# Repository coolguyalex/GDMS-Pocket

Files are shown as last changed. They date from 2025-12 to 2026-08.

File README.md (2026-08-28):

# GDMS:Pocket
**Goblinoid Dungeon Mastering System** — microcontroller-based handheld random table roller for tabletop RPGs.

---

## Concept

A dungeon master's companion designed to stay out of the way until you need it. Pull it out, roll a name, an encounter, a room, or whatever your table demands, then put it back in your pocket. GDMS:Pocket is designed to be as ignorable as it is useful — no app, no screen glare, no dead battery notification from your phone mid-session.

Content lives on a microSD card as plain CSV files and JSON recipe files. Adding, removing, or editing tables requires nothing more than a computer and a text editor.

---

## Current Firmware: Alpha 10 

### Implemented Features

- Navigate categories corresponding to folders on the SD card
- Browse and select CSV tables or JSON recipe generators within each category
- Roll a random result with a single button press; re-roll instantly with the same button
- Scroll long results that exceed the screen height
- Hold UP/DOWN for fast scrolling through lists
- LED breathing animation indicates power-on state
- LED "pop" flash on every button press
- Passive buzzer feedback — distinct tones per button
- Full options menu (A+B combo from any screen):
  - Buzzer on/off and volume (loud/soft)
  - LED on/off, pop on/off, brightness (low/med/high)
  - Breath speed (fast/med/slow)
  - Sleep timeout (5 min / 10 min / 30 min / never)
  - Data Edit Mode — exposes the SD card as a USB mass storage drive
- Settings persist to SD card (`/DATA/settings.cfg`) and reload on boot
- Sleep mode: display blanks after inactivity timeout; any button wakes it (suspended while in Data Edit Mode)
- Live battery voltage indicator in the header — 3-bar icon with critical flash
- Header titles truncated with `...` if they would overlap the battery icon
- Startup splash screen (2 seconds on boot)
- About screen with control reference

### Data Edit Mode

Selecting "Data Edit" from the options menu puts the device into USB mass storage mode: the SD card mounts on the connected computer as a normal removable drive, so content can be added, edited, or removed with a regular file explorer — no card removal required. The device still charges normally over the same USB-C connection while in this mode.

- Entered from the options menu (A → cycles into the mode)
- Screen displays "DATA EDIT MODE" / "press A + B to exit." while active
- Exit via A+B (held) — the same combo used elsewhere to open the options menu is repurposed here to exit, since the options menu isn't reachable while the SD card is handed off to the host
- On exit, the SD card is unmounted from the host, remounted for the firmware's own file access, and categories are rescanned so any added/removed/edited content shows up immediately
- Implemented via Adafruit_TinyUSB's mass storage (MSC) class, using the same SdFat `SD` object already used for file-level access elsewhere in the firmware — read/write/flush callbacks operate at the raw sector level rather than the file level
- Sleep timeout is disabled while in this mode so the screen doesn't blank mid-transfer

### JSON Recipe System (V1)

JSON files in a category folder act as multi-part generators. A recipe chains together rolls from multiple CSV tables and assembles them into a single composed output. Features include optional parts (probability `p`), repeat counts, cross-category table references, and a `format` string for custom output layouts. See **Content & Customisation** below and the recipe convention document in the repo for full details.

### CSV Weighted Tables

If a CSV file uses two columns — `weight,entry` — the first column is treated as an integer weight and results are sampled proportionally. Single-column CSVs treat all entries as equally likely. Lines beginning with `#` or `//` are treated as comments and skipped.

---

## Hardware

### Bill of Materials

| Component | Description |
|---|---|
| Adafruit Feather RP2040 Adalogger | MCU + built-in microSD slot |
| 1.5" SH1107 OLED (SPI, 128×128) | Display |
| 4× momentary pushbutton | Navigation (active-low) |
| Passive buzzer module (3-pin) | Audio feedback |
| LED + current-limiting resistor | Status indicator |
| 3.7V LiPo battery (JST connector) | Power |
| 2× 100kΩ resistor | Battery voltage divider |

### BOM with cost estimates
|Component |Price |Source |
|---|---|---|
|Adafruit Feather RP2040 Adalogger |$14.95 |Adafruit / DigiKey, retail single unit|
|1.5” SH1107 128×128 monochrome OLED (SPI)|$4.50 |AliExpress, bulk 10-pack pricing |
|Momentary pushbuttons ×4 |$0.60 |AliExpress, bulk 100pc pack |
|Passive buzzer module |$0.35 |AliExpress, bulk pack |
|LED + resistor |$0.10 |AliExpress, bulk pack |
|3.7V LiPo battery w/ JST |$2.50 |AliExpress, bulk pack |
|100kΩ resistors ×2 |$0.02 |AliExpress, bulk reel |
|Slide switch |$0.30 |AliExpress, bulk pack |
|Custom PCB, bare board (10-unit batch) |$1.50 |PCBWay |
|3D printed PETG enclosure |$3.00 |Self-sourced filament |
|Misc wire/headers/hardware |$1.00 |AliExpress, bulk pack |
|**Total** |**$28.82**| |

### Pin Mapping

#### OLED Display (SH1107, Software SPI)

| OLED Pin | Feather Pin |
|---|---|
| VCC | 3V3 |
| GND | GND |
| SCL (CLK) | D13 |
| SDA (DATA) | D12 |
| DC | D11 |
| CS | D10 |
| RST | D9 |

> **Library patch required:** The U8g2 SH1107 128×128 driver sets `default_x_offset = 96` by default, which causes a 32px horizontal wrap on some panels. Set both `default_x_offset` and `flipmode_x_offset` to `0` in `u8x8_d_sh1107.c`. This must be re-applied after any U8g2 library update. See Log 8 for full details.
>
> This has recurred at least once in practice after installing an unrelated library (Adafruit TinyUSB) via Library Manager, which appears to have triggered a U8g2 reinstall/update as a side effect. Worth checking `default_x_offset`/`flipmode_x_offset` any time the display shows an unexplained horizontal shift, not just after deliberate U8g2 updates. As of U8g2's source (checked Feb 2025), the maintainer's own comment on this section confirms `0` is the correct value for panels like this one — see [olikraus/u8g2#2581](https://github.com/olikraus/u8g2/issues/2581).

#### Buttons (Active-Low, Internal Pull-Up)

| Button | Feather Pin |
|---|---|
| UP | A1 |
| DOWN | A2 |
| A (select / roll) | A3 |
| B (back) | 24 |

Buttons are wired pin → GND. No external pull-up resistors needed.

#### Buzzer (Passive, PWM)

| Signal | Feather Pin |
|---|---|
| SIG | D6 |
| VCC | 3V3 |
| GND | GND |

> A series resistor (~1kΩ) on the signal line is recommended to reduce volume to a comfortable level for table use.

#### LED

| Connection | Feather Pin |
|---|---|
| Anode (via resistor) | D25 |
| Cathode | GND |

> Do not use `PIN_LED` as a variable name — it is defined as a macro in the RP2040 Arduino core.

#### Battery Voltage Divider

The Feather RP2040 Adalogger does not have a built-in battery monitor circuit. An external voltage divider must be wired as follows:

```
VBAT ──[ 100kΩ ]──┬──[ 100kΩ ]── GND
                  │
                  └── A0
```

| Signal | Feather Pin |
|---|---|
| Divider center tap | A0 |

The firmware reads A0, multiplies by 2, and displays a 3-bar battery icon in the header. Voltage thresholds: FULL ≥4.0V, OK ≥3.7V, LOW ≥3.5V, CRIT <3.5V (flashing).

### SD Card

The Adalogger's built-in microSD slot is used via SdFat (Adafruit fork) on SPI1. Format the card as FAT32.

---

## SD Card Data Structure

```
/DATA/
  /category-name/
    table.csv
    generator.json
    _hidden-ingredient.csv
  /another-category/
    ...
  settings.cfg          ← written automatically by firmware
```

- `/DATA` is the root content directory. It must exist.
- Each immediate subfolder of `/DATA` becomes a navigable category in the UI.
- Folders nested deeper than one level are ignored.
- `.csv` and `.json` files within a category folder appear as selectable items.
- Files whose names begin with `_` are hidden from the UI but accessible to JSON recipes.
- `settings.cfg` is written automatically and should not be edited manually.

---

## Software

### Language & Framework

Arduino (C++) targeting the Adafruit Feather RP2040 Adalogger via the Arduino-Pico core.

### Library Dependencies

| Library | Purpose |
|---|---|
| U8g2 (olikraus) | OLED driver and graphics |
| SdFat – Adafruit Fork | microSD access |
| ArduinoJson | JSON recipe parsing |
| Adafruit TinyUSB | USB mass storage (Data Edit Mode) — requires Tools > USB Stack > Adafruit TinyUSB in Arduino IDE |

### Controls Reference

| Button | Category / File list | Table / Result view | Options menu | Data Edit Mode |
|---|---|---|---|---|
| UP | Scroll up | Scroll up | Previous option | — |
| DOWN | Scroll down | Scroll down | Next option | — |
| A | Select / enter | Re-roll | Cycle setting value | — |
| B | — (no-op at root) | Back to file list | Back | — |
| A + B (held) | Open options | Open options | — | Exit Data Edit Mode |

### Architecture Notes

- State machine with six modes: `MODE_CATS`, `MODE_FILES`, `MODE_TABLE`, `MODE_OPTIONS`, `MODE_ABOUT`, `MODE_DATA_EDIT`
- Page-buffer OLED rendering (`_1_` constructor) — redraws on input events only, with a periodic background refresh for animation (LED breath, battery icon flash)
- Non-blocking LED and buzzer using `millis()` timers throughout
- Battery sampled every 5 seconds via a non-blocking timer; 8-sample average
- All user settings persisted to `/DATA/settings.cfg` as key=value text immediately on change
- SD card is accessed two ways depending on mode: file-level (`SD.open()`, `FsFile`) for normal category/table browsing, and raw block/sector-level (`SD.card()->readSector()`/`writeSector()`) for Data Edit Mode's USB mass storage exposure — same underlying SdFat object, different API surface

---

## Planned / Future Features

- Auto-mode: a dearf-fortressian ambient atory generatir where randomyl generated entires drive a strange atory which unfolds before the reader. 
- Per-category icons (`_icon.bin`, 32×32 1-bit bitmap) rendered in the header
- Saved results — up to 10 entries written to SD, browsable on a Saved page
- Nested JSON recipes (recipes invoking other recipes)
- Ambient mode — auto-rolls at a set interval for generative table atmosphere
- Neopixel indicator
- Battery voltage shown in the About screen
- Migration from `StaticJsonDocument` to `JsonDocument` (ArduinoJson v7 alignment)
- **GDMS-pocket Companion App** — desktop tool for content authoring, generation, and firmware flashing (see below)

---

## GDMS-pocket Companion App (Planned)

A desktop companion tool for authoring and managing GDMS:Pocket content, shipped alongside the device rather than as a separate purchase. Not yet implemented — this section documents the intended design and open questions.

### Concept

**Data Edit Mode is now implemented on-device** (see Current Firmware above) — the SD card can be exposed as a plain USB mass storage drive from the options menu, no companion app required. The companion app remains planned as a richer, GDMS-aware layer on top of this: same name family, same visual language, same spirit of staying out of the way until needed, but with content-authoring tools (Markov-chain generation, structured CSV/JSON editing, firmware flashing) that a generic file explorer can't offer.

### Aesthetic

Black-on-green CLI-style interface, matching the terminal look of the original [GDMS](https://github.com/coolguyalex/GDMS) desktop tool. Navigation is entirely text-based:
- Keyboard shortcuts for every applet/action
- Clickable text labels as the mouse-driven alternative — text glows on hover and blinks briefly when clicked, echoing a terminal cursor rather than a conventional button

### Device Detection & Interaction

Still an open design question — rough intent:
- When the app is running and a GDMS:Pocket is connected via USB, the device should detect the companion app's presence (likely via a simple serial handshake) and unlock companion-aware functionality on-device, going beyond the generic mass-storage exposure Data Edit Mode already provides.
- Once connected, the app could:
  - Browse and directly edit category folders, CSV tables, and JSON recipes on the SD card
  - Generate new content — e.g. Markov-chain-based text generators trained on existing tables, to bootstrap new CSV entries from a sample of existing ones
  - Flash new firmware to the device (bundling firmware updates with the same tool used for content, instead of requiring separate Arduino IDE / bootloader steps)
  - **Chiptune mode** (low priority / just for fun) — compose or import chiptune-style songs and play them back through the device's passive buzzer, in the spirit of [goblinoidDungeonSynthSystem](https://github.com/coolguyalex/goblinoidDungeonSynthSystem)

### Open Questions

- ~~Whether "Data Edit Mode" on the device becomes a distinct on-device mode of its own, or stays implicit~~ — resolved: it's a distinct on-device mode, entered/exited explicitly from the options menu, and works as plain mass storage independent of any companion app
- Whether the companion app's smarter feature set (content generation, firmware flashing) talks to the device over serial while Data Edit Mode's plain mass-storage exposure remains the fallback for basic editing
- How much of the companion-aware logic should live in GDMS:Pocket firmware itself (e.g. a lightweight serial command protocol) vs. entirely in the companion app

---

## Changelog

| Version | Summary |
|---|---|
| Alpha 10| Data Edit Mode (USB mass storage for SD card content editing) |
| Alpha 9 | Battery voltage icon in header, header truncation, stale pin comment fixed |
| Alpha 8 | Scrollbar on category list, additional LED options |
| Alpha 7 | Sleep/wake, scrollbar in table view, About screen in options |
| Alpha 6 | A+B combo options menu |
| Alpha 5 | LED breathing and pop animations |
| Alpha 4 | List scrolling |
| Alpha 3 | Hold-to-scroll on UP/DOWN |
| Alpha 2 | Word-aware line wrapping |
| Alpha 1 | Initial SH1107 bring-up, pin map, full hardware test |

---

*GDMS:Pocket by Alexander Sousa, 2026*

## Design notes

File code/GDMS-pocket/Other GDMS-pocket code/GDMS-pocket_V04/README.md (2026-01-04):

Version 4 was written in circuit python for the adafruit RP2040 adalogger

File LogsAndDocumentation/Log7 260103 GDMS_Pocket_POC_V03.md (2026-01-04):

# GDMS-Pocket POC Dev Log (POC_V03)

Date: 2026-01-04  
Target: Adafruit RP2040 Adalogger + 0.96" SSD1306 OLED + 4 buttons + LED + passive buzzer + SD card

## Goal of this POC
Implement the core “random table rolodex” loop described in the README:

- Browse category folders under `/DATA`
- Browse `.csv` tables inside a category
- Pick a table and “roll” a random entry from it (re-rollable)  
【119:3†README.md†L31-L66】

This session focused on building that end-to-end loop (folders → files → random row) plus a set of UI refinements needed for the specific OLED you’re using.

---

## Hardware + Wiring (as used in code)
- OLED: SSD1306 128×64, I²C (0x3C), `Wire` at 400kHz
- Buttons (active LOW w/ `INPUT_PULLUP`)
  - Up: D9
  - Down: D10
  - A: D6 (Open / Select)
  - B: D5 (Back)
- LED: D11 (PWM dim blink on press)
- Passive buzzer: D12 (short tones on press)

(Buttons were explicitly remapped so **A = open/select** and **B = back** to match the intended UX.)

---

## SD data layout (POC assumptions)
- SD has `/DATA` at the root.
- `/DATA/<CATEGORY>/` contains one-level-deep category folders only (no recursion).
- Each category folder contains `.csv` files representing random tables.  
【119:3†README.md†L36-L52】

---

## What’s working now (end-to-end behavior)

### 1) Category browser (MODE_CATS)
- On boot, the system scans `/DATA` and builds an in-memory list of category folder names.
- UI shows a scrollable list with a cursor (">").
- Header uses a smaller font and is positioned so list text stays out of the OLED’s yellow top band.
- Footer/tooltips removed (controls are intuitive).

### 2) File browser (MODE_FILES)
- When a category is opened, the system scans `/DATA/<selectedCat>/` and lists `.csv` files only.
- UI shows scrollable list with cursor.
- Filenames are displayed **without the `.csv` extension** (via `stripCsvExt()`).
- Long names are truncated with ellipses (`ellipsize()`), preventing wrap into a second line.

### 3) Table view + rolling (MODE_TABLE)
- Selecting a file constructs `fullPath = "/DATA/" + selectedCat + "/" + selectedFile`.
- `pickRandomCsvLine()` selects a random non-empty line from the file using **reservoir sampling**.
- Table view displays the selected entry using a simple fixed-width wrap.
- A reroll:
  - Re-runs `pickRandomCsvLine()`
  - Increments `rollCount`
- B goes back to the file list.

### 4) Table scrolling (Up/Down in MODE_TABLE)
- Long generated entries can be scrolled using Up/Down.
- Scroll operates in “wrapped line” units:
  - `countWrappedLines()` estimates wrapped line count using a fixed chars-per-line assumption.
  - `tableScrollLine` is clamped to valid range.
- **Important reset point:** whenever entering MODE_TABLE (selecting a file) we reset:
  - `rollCount = 0`
  - `currentEntry = ""`
  - `tableScrollLine = 0` (so each new table starts at top)

---

## UI changes made for your specific OLED
### Yellow top band avoidance
Your OLED has a yellow pixel band at the top. We adjusted the layout so *all list/table text starts below that band*:

- Reduced header font size (general change: headers are now small font)
- Adjusted header divider and list start `y0` values:
  - You found `y0 = 16` works best on your specific module (keeps content in the blue region).

### List layout / removing overlap
- Previously the bottom row could collide with the footer/tooltips.
- We removed the footer entirely and sized lists so the last list row stays clear of the bottom edge.

### Filename and entry wrapping fixes
- `.csv` extension hidden in file list display (reduces line length)
- Long list items ellipsized to a safe character count
- Table entries wrapped and scrollable

---

## Key implementation notes (so a dev can continue quickly)

### Core state machine
`UiMode`:
- `MODE_CATS`: category list
- `MODE_FILES`: csv list for selected category
- `MODE_TABLE`: currentEntry + reroll + scroll

State variables (high level):
- Category: `categories[]`, `catCount`, `cursor`, `scrollTop`
- Files: `files[]`, `fileCount`, `fileCursor`, `fileScrollTop`
- Table: `selectedCat`, `selectedFile`, `currentEntry`, `rollCount`, `tableScrollLine`

### Random CSV selection
`pickRandomCsvLine(fullPath, outLine)`:
- Reads file line-by-line (fixed buffer)
- Trims CR/LF
- Skips empty lines and comment-ish lines (`#`, `//`)
- Reservoir sampling chooses 1 random line from unknown-length stream (no need to load file into RAM)

### Input + feedback
- Buttons use edge detection + debounce.
- On press:
  - PWM LED blink at a very low brightness
  - Buzzer tone for 30ms (frequency varies per button)

---

## Known issues / TODOs
1) **Header wrap on long table names**
   - Example: `motivations.csv` sometimes renders as `motivation` then `s` (wrap), which can overlap content.
   - Fix: header should always be ellipsized to fit one line (or rendered with text bounds and clipped).

2) **Category screen not using full vertical space (list height)**
   - You noticed categories don’t extend to the bottom as expected.
   - Fix: revisit `rows`, `listY0`, and the available height calculation to ensure consistent use of 64px height on all screens.

3) **CSV “weighted two-column” support not implemented yet**
   - README calls for interpreting 2-column CSV weights. This is not in the current POC loop.  
   【119:3†README.md†L7-L13】

4) **JSON “recipes” chaining not implemented yet**
   - Out of scope for POC_V03, but in the README “additional functionality” list.  
   【119:3†README.md†L7-L13】

---

## Suggested next step (minimal + high value)
**Header ellipsize + single-line guarantee**
- Create `String headerSafe(const String& s)` that:
  - strips `.csv`
  - ellipsizes to a max character count for the header font
- Apply to:
  - file list header (selectedCat)
  - table header (selectedFile)

Then, unify layout constants:
- `HEADER_H`, `CONTENT_Y0`, `ROWS_PER_LIST`
so the category screen and file screen stay consistent.

---

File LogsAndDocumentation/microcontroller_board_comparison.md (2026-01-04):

# Microcontroller Board Comparison (Hobbyist-Focused)

*Prices are approximate single-board retail. Community size is a qualitative estimate based on forums, tutorials, libraries, and third‑party projects.*

| Board | MCU | CPU / Speed | RAM (SRAM) | Flash | Connectivity | Typical Price (USD) | Community Size | Notable Features / Gotchas |
|---|---|---:|---:|---:|---|---:|---|---|
| Raspberry Pi Pico | RP2040 | Dual-core Cortex-M0+ @ 133 MHz | 264 KB | 2 MB QSPI | USB | ~$4 | **Very Large** | PIO is extremely powerful; massive docs and examples |
| Raspberry Pi Pico W | RP2040 + CYW43439 | Dual-core @ 133 MHz | 264 KB | 2 MB | Wi‑Fi | ~$6 | **Very Large** | Wireless Pico without ESP32 complexity |
| Seeed XIAO RP2040 | RP2040 | Dual-core @ 133 MHz | 264 KB | 2 MB | USB | $5–$10 | **Large** | Ultra‑small form factor, strong Seeed ecosystem |
| Adafruit Feather RP2040 | RP2040 | Dual-core @ 133 MHz | 264 KB | 4–8 MB (varies) | USB | $10–$15 | **Very Large** | Feather ecosystem, LiPo charging, polished UX |
| Adafruit Feather RP2040 Adalogger | RP2040 | Dual-core @ 133 MHz | 264 KB | 8 MB + microSD | USB | $14.95 | **Very Large** | Built‑in SD + datalogging focus |
| Elegoo Nano (Nano V3 clone) | ATmega328P | 8‑bit AVR @ 16 MHz | 2 KB | 32 KB | USB | Very cheap | **Huge (Legacy)** | Arduino classic; RAM is extremely tight |
| Arduino Nano Every | ATmega4809 | AVR @ 20 MHz | 6 KB | 48 KB | USB | ~$10 | **Large** | Still 5V; more headroom than 328P |
| Arduino Nano R4 | Renesas RA4M1 (Cortex‑M4) | 48 MHz | 32 KB | 256 KB | USB | $12 | **Growing** | Modern Nano, 32‑bit, strong Arduino backing |
| ESP32 (WROOM‑32) | ESP32 (Xtensa LX6) | Dual-core up to 240 MHz | 520 KB | External SPI (4 MB common) | Wi‑Fi + BT | $5–$10 | **Huge** | Wireless king; more software complexity |
| ESP32‑S3 Dev Board | ESP32‑S3 | Dual-core up to 240 MHz | On‑chip + PSRAM (varies) | External SPI | Wi‑Fi + BLE | $7–$15 | **Very Large** | Native USB, AI/graphics friendly |
| STM32 “Blue Pill” | STM32F103 | Cortex‑M3 @ 72 MHz | 20 KB | 64 KB | USB | $2–$5 | **Medium** | Clone quality varies; toolchains less friendly |
| STM32 Nucleo‑F401RE | STM32F401RE | Cortex‑M4 @ 84 MHz | 96 KB | 512 KB | USB | ~$15 | **Large (Pro‑leaning)** | On‑board debugger; industry‑style workflows |
| Teensy 4.0 | i.MX RT1062 | Cortex‑M7 @ 600 MHz | 1 MB | 2 MB | USB | ~$16 | **Large (Advanced)** | Insane performance; great audio/DSP support |

## Community Size Key
- **Huge**: Arduino / ESP32 scale, thousands of tutorials and libraries
- **Very Large**: RP2040 + Adafruit ecosystems
- **Large**: Active forums, regular new projects
- **Growing**: Strong backing but newer ecosystem
- **Medium**: Knowledgeable users, fewer beginner guides

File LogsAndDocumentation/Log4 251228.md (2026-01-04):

# GDMS micro – Development Log & Architecture Notes  
**Author:** Alexander Sousa  
**Date:** 2025  
**Platform:** Arduino micro–class (ATmega328P, Elegoo nano clone)  
**Display:** SSD1306 128×64 OLED (I²C) using U8x8 text mode  

---

Important Note -- Project pivotted from GDMS pocket to GDMS micro to create something that could exist on an elegoo nano, a clone of an outdated verison of the arduino nano independent of SD cards. a standalone device with no adaptive menus or user-addable content. 

## 1. Project Goal (High-Level)

GDMS micro is a **single-purpose, table-facing Dungeon Master aid** designed to provide:

- Instant inspiration  
- Fast multi-roll results (NPCs, rooms, encounters)  
- A tactile, distraction-free alternative to laptops and phones  

Design philosophy:
- **Finite, intentional, offline**
- No search, no editing, no scrolling feeds
- Curated content over infinite content
- Physical buttons + simple screen = ritual tool, not software suite

---

## 2. Hardware Constraints (Critical)

**MCU:** ATmega328P (Elegoo micro clone)  
- Flash: ~30 KB usable  
- SRAM: 2 KB total  

These constraints strongly shape all design decisions.

Key implications:
- Dynamic memory must be tightly controlled
- Avoid heap usage (`String`, dynamic allocation)
- All large/static text must live in flash (PROGMEM)
- UI complexity must be minimal

---

## 3. Major Technical Decisions Made

### 3.1 Switched from U8g2 to U8x8

**Reason:**  
U8g2 font rendering consumed excessive flash memory.

**Outcome:**
- Program flash usage dropped from ~75% to ~36%
- SRAM usage dropped to ~38%
- Freed ~19 KB flash for future content (tables, generators)

**Tradeoff:**
- Text-only UI (16 columns × 8 rows)
- No proportional fonts
- 2×2 text scaling available via `draw2x2String()`

This aligns well with the Shadowdark / minimalist aesthetic.

---

### 3.2 Fixed Buffers + PROGMEM Everywhere

**Key pattern adopted:**
```cpp
char buffer[16];   // fixed-size RAM buffer
```

- All tables and strings stored in PROGMEM
- Only the selected result is copied into RAM
- Prevents heap fragmentation and crashes

**Rule established:**  
RAM holds *only what is currently visible or being processed*.

---

## 4. System Architecture Introduced

### 4.1 Applet-Based UI Model

The system now uses a **two-layer state machine**:

#### UI Mode
```cpp
enum UiMode { MODE_HOME, MODE_APPLET };
```

- `MODE_HOME`: select which applet to use
- `MODE_APPLET`: interact with the selected applet

#### Applet Selection
```cpp
enum Applet { APP_DICE, APP_NAMES, APP_ROOM };
```

- Applets are **features**, not data
- Applet list is intentionally small and curated
- SD-card dynamism (future) belongs *inside* applets, not at the top level

---

### 4.2 Button Semantics by Mode

Same physical buttons, different meaning depending on context:

#### HOME Mode
- `<` / `>` : cycle applets
- `X` : enter selected applet

#### APPLET Mode
- Applet-specific behavior
- **Exit gesture:** hold `<` + `>` simultaneously to return HOME

---

### 4.3 Draw Responsibility Separation

Drawing is now explicitly separated:

```cpp
void drawHome();
void drawDice();
void drawNames();
void drawRoom();
void drawUi();
```

- Drawing functions never change state
- Button logic never draws directly
- `drawUi()` is the only rendering entry point

---

## 5. Applets Implemented

### 5.1 Dice Applet
- Cycles through D4 → D100
- X rolls the selected die
- Displays result in 2×2 text
- Buzzer pitch mapped to die size
- LED pop feedback

Status: **Complete and stable**

---

### 5.2 Names Applet
- Single flat list of names
- X picks a random name
- Names stored in PROGMEM
- Selected name copied into fixed buffer

Status: **Placeholder, expandable**

---

### 5.3 Room Applet
Chained generator producing:
- Size
- Feature
- Threat
- Exit

Status: **Flagship proof-of-concept**

---

## 6. Splash Screen
- Displays on startup only
- 2-second delay
- Implemented in `setup()`

---

## 7. Memory Snapshot

```
Sketch uses 11,346 bytes (36%) of program storage.
Global variables use 794 bytes (38%) of dynamic memory.
```

---

## 8. Lessons Learned

- State machines simplify UI scaling
- Fonts are often the largest flash cost
- Fixed buffers prevent instability
- Compression of effort beats feature bloat

---

## 9. Future Work
- Names applet: ancestry selection
- SD-backed table browsing
- NPC chained generator
- Optional RP2040 migration

---

## 10. Design Guardrails

- No free text entry
- No search
- No rules enforcement
- No persistent campaign state

**GDMS micro suggests. The DM decides.**

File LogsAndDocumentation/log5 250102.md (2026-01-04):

Working with:
-  the RP2040 adalogger feather board by adafruit
- 2.13" ePaper Tri-color feather wing with stacking headers for the adalogger

Switched to CircuitPython

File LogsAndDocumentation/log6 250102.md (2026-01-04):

# GDMS Pocket – Development Log

**Date:** 2026-01-02  
**Hardware Platform:** Adafruit Feather RP2040 Adalogger  
**Goal:** Validate display options and bring up core I/O (buttons, LED, buzzer) in preparation for GDMS Pocket firmware development.

---

## 1. E‑Paper (eInk) Display Exploration

### Hardware Tested
- Adafruit 2.13" Tri‑Color eInk FeatherWing (SSD1680)
- Integrated directly onto the Feather RP2040 via Feather headers

### Goals
- Evaluate e‑paper as a low‑power, high‑legibility display option
- Assess refresh behavior and suitability for menu‑driven interaction

### Findings
- The e‑paper FeatherWing integrates cleanly at the hardware level.
- Full refresh behavior is inherent to the technology:
  - Refreshes are slow compared to OLED
  - Visible flashing during refresh is unavoidable
- Partial refresh support is limited and highly controller‑specific.
- The display is best suited for:
  - Static information
  - Infrequently changing screens
  - “Page‑based” interaction rather than cursor‑based UI

### Conclusion
While visually appealing and power‑efficient, e‑paper was deemed **not ideal for early GDMS Pocket prototyping**, where:
- Rapid iteration
- Frequent screen updates
- Cursor‑based menus

are required. The e‑paper display remains a **strong candidate for future variants** or alternative builds focused on ultra‑low power or static reference use.

---

## 2. OLED Bring‑Up and System Integration

### Display
- 0.96" SSD1306 I²C OLED (128×64, monochrome)

### Wiring Validation
- I²C (SDA/SCL) connected to Feather defaults
- OLED powered from 3V rail
- Successful I²C device scan confirmed communication

### CircuitPython Setup
- Required libraries:
  - `adafruit_ssd1306`
  - `adafruit_framebuf`
- Resolved missing `font5x8.bin` error by:
  - Adding font file to CIRCUITPY root
  - Verifying text rendering functionality

### Graphics Capabilities Confirmed
- Full framebuffer access (1‑bit, 128×64)
- Successful use of:
  - Text rendering
  - Filled rectangles
  - Simple animation
- Determined that CircuitPython + SSD1306 is sufficient for:
  - Menus
  - Icons
  - Cursors
  - Simple UI animation

### Button Bring‑Up
- Four momentary buttons wired using internal pull‑ups:
  - Active‑low (button to GND)
- Final functional mapping (after discovery of swapped wiring):
  - Physical UP / DOWN / A / B correctly detected
- Verified via serial console event logging

### LED Test
- External green LED on pin D11
- Confirmed:
  - Proper current limiting resistor
  - GPIO control
  - Stable blinking behavior

### Buzzer Test
- Passive buzzer wired:
  - + to D12
  - − to GND
- PWM audio output tested successfully
- Confirmed tone generation and duty‑cycle control

### System Status
At the end of this session, the following components are fully operational under CircuitPython:

- OLED display (graphics + text)
- Four buttons (reliable input)
- Status LED
- Passive buzzer

This establishes a **solid hardware and firmware foundation** for moving on to:
- UI layout work
- Menu navigation logic
- Applet/page architecture
- GDMS Pocket core features

---

**Next Steps (Deferred):**
- Unified input + display UI loop
- Menu/cursor rendering
- Dice and table navigation logic
- Storage integration strategy

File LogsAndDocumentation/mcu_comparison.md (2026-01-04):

# MCU Comparison Table

| MCU / Board | Release (approx) | MCU | CPU / Clock | SRAM | Flash | Wireless | Typical Notes |
|---|---|-----|---|---|---|---|---|
| Elegoo Nano (Arduino Nano clone) | ~2016 (clone era) | ATmega328P | 8-bit AVR @ 16 MHz | 2 KB | 32 KB | No | Very limited RAM, tight for SD + display, good for learning basics |
| Arduino Nano Every | 2019 | ATmega4809 | 8-bit AVR @ 20 MHz | 6 KB | 48 KB | No | Slightly more RAM than Nano, still constrained but more usable |
| Arduino Uno R4 WiFi | 2023 | Renesas RA4M1 (Cortex-M4F) + ESP32-S3 | 48 MHz (RA4M1) | 32 KB | 256 KB | Yes (ESP32-S3) | Modern MCU, good peripherals, wireless adds complexity |
| SAMD21 (M0+) | ~2014 | Cortex-M0+ | 48 MHz | 32 KB | up to 256 KB | No | Low power, limited RAM for UI-heavy work |
| RP2040 | 2021 | Dual Cortex-M0+ | 133 MHz | 264 KB | External QSPI | No | Excellent RAM for SD/UI, weaker deep sleep |
| ESP32 (original) | 2016 | Xtensa LX6 | up to 240 MHz | ~520 KB | External (module) | Yes | Powerful, good sleep, WiFi can dominate power |
| STM32F4 (example) | ~2011 | Cortex-M4F | up to 168 MHz | up to 192 KB | up to 1 MB | No | Powerful but older and less power-efficient |

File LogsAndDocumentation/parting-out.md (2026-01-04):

# cost for cheap as possible unit capable of playing a game 

## parts 

|Part|Qty|Unit Price|Price Total|
|---|---|---|---|
|nano clone|
|0.96" oled |
|battery
|

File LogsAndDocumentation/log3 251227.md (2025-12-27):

# GDMS Pocket -- Iteration Log (AVR / Arduino Nano Every)

## Project Context

This iteration focused on porting the Goblinoid Dungeon Mastering System
(GDMS) to an Arduino-class microcontroller with extremely limited SRAM
(\~2 KB). The goal was a handheld Dungeon Master aid that reads random
table entries from text files on an SD card and displays results on a
small OLED screen, with physical buttons and a status LED.

## Hardware Used

\- Arduino Nano Every (AVR-class SRAM constraints)\
- SSD1306 128x64 OLED (I2C)\
- SPI microSD card module\
- Three momentary buttons (LEFT / MIDDLE / X)\
- Green LED on D6 (PWM) with series resistor

## Features Successfully Implemented

\- Reliable SD card initialization and file reading\
- Reservoir sampling to select random lines from large text files
without loading them into RAM\
- OLED display output using U8g2 page-buffer mode\
- Button debounce logic with edge detection\
- LED status indicator with:\
• low-power breathing animation (\~1 second cycle)\
• short brightness \'pop\' on button presses\
- Clean separation between setup() initialization and loop() runtime
behavior

## Key Problems Encountered

1\. \*\*Severe SRAM pressure\*\*\
- Global memory usage reached \~91%, leaving \~180 bytes free\
- Resulted in reset loops, freezes during SD directory scans, and
unstable behavior\
\
2. \*\*Arduino auto-prototype conflicts\*\*\
- Functions using custom structs (DebounceBtn) and SD File types caused
compiler errors\
- Name collisions (isTxtFile, readLine) triggered \'redeclared as
different kind of symbol\' errors\
\
3. \*\*Directory traversal instability\*\*\
- openNextFile() directory scans during setup() caused hangs and resets
under low SRAM\
- Progress/debug buffers worsened stack usage\
\
4. \*\*Misleading memory reporting\*\*\
- Flash usage (\~80--88%) was not the problem\
- SRAM usage was the real limiting factor

## Solutions and Workarounds

\- Renamed SD helper functions (sdIsTxtFile, sdReadLine) to avoid
auto-prototype collisions\
- Reduced global buffer sizes aggressively\
- Moved toward non-blocking LED and button logic\
- Identified directory scanning at boot as a major instability source\
- Confirmed LED breathing stopped when setup() stalled, helping diagnose
hangs

## Features Explicitly Shelved for This Board

\- User-added tables via arbitrary SD folder browsing\
- Recursive directory traversal\
- Dynamic table discovery at boot\
- Rich OLED layouts beyond basic text

## Recommended AVR-Safe Design (If Revisited)

\- Use U8x8 (text-only) instead of U8g2 to reclaim \~150--400 bytes
SRAM\
- Hard-code a small list of table file paths (no directory scanning)\
- Keep line buffers ≤ 21--25 characters\
- Avoid snprintf(), lambdas, and temporary local buffers\
- Treat SD access as a high-risk operation under low SRAM

## Reason for Pausing This Iteration

The remaining SRAM margin on the Nano Every is too small to safely
support SD access, OLED UI, button handling, and future expansion
simultaneously. Continuing to optimize would significantly constrain
functionality and developer time.

## Next Planned Platform

RP2040-based board (e.g., Adafruit Feather RP2040 / Adalogger)\
- \~264 KB SRAM eliminates current constraints\
- Built-in USB, better SD support, and more robust multitasking\
- Allows restoring:\
• user-addable tables\
• directory browsing UI\
• richer screen layouts\
• future chained table generation

## Current Project State

The AVR prototype successfully validated:\
- core SD streaming approach\
- random table selection algorithm\
- LED and button interaction patterns\
\
Development is paused intentionally until migration to RP2040 hardware.

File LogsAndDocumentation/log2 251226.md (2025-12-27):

# GDMS:Pocket -- Incremental SD + OLED Development Report 251216

This document summarizes the step-by-step development process used to
implement a low-RAM, microcontroller-based Dungeon Master table roller
using an SSD1306 OLED display, an SPI SD card module, and physical
buttons. The goal of this report is to allow future-you or another
developer to reproduce the same working system and understand the
reasoning behind each technical decision.

## Target Platform

- Arduino-class MCU (Uno / Nano / Nano Every)
- Severe RAM constraints (~2 KB SRAM)
- SPI SD card reader module (with onboard regulator)
- SSD1306 OLED via I²C
- Momentary buttons wired to GND (INPUT_PULLUP)

## Key Constraints Identified Early

1. RAM is the primary limiting factor.
2. SD card access causes brief current spikes.
3. Many SD modules do NOT operate correctly when powered from 3.3V
despite claims.
4. Arduino SD.h uses FAT 8.3 short filenames only.
5. Directory iteration requires explicit rewindDirectory() calls.

## Verified Hardware Findings

- SSD1306 OLED works reliably at both 3.3V and 5V.
- SD module reliably initializes only when powered from 5V.
- SD activity can cause visible LED flicker due to rail sag.
- SD card access must be minimized during runtime.

## File System Rules Adopted

- All folders live at SD root.
- Folder and file names must be FAT 8.3 compliant.
- Example structure:

        /DICE
            /D20.TXT
            /D100.TXT

## Development Phases

### Phase 1: OLED Bring-Up

- Tested OLED independently.
- Confirmed rotation using U8G2_R2.
- Chose U8g2 page buffer (_1_) to conserve RAM.

### Phase 2: SD Initialization

- Verified SD.begin() stability.
- Identified 5V requirement for SD module.
- Avoided SPI reconfiguration once stable.

### Phase 3: Root Directory Enumeration

- Successfully listed root folders.
- Observed 8.3 short-name behavior (ENCOUN~1, etc.).
- Learned that renaming folders does not always remove aliasing.

### Phase 4: Folder Traversal

- Opened /DICE folder directly.
- Discovered openNextFile() returns no entries without
rewindDirectory().
- Confirmed correct file count after rewind.

### Phase 5: File Reading

- Implemented line-by-line file reading.
- Avoided String objects entirely.
- Read only first line initially to validate path correctness.

### Phase 6: Random Line Selection

- Implemented reservoir sampling for uniform randomness.
- Required only constant memory regardless of file size.
- Proven reliable with large tables.

### Phase 7: Button Integration

- X button (D4) triggers a reroll.
- Implemented debounce and edge detection.
- SD access occurs only on button press.

## Final System Behavior

- Device boots to "Ready" state.
- Pressing X opens a table file and rolls a random entry.
- Result is displayed on OLED.
- System remains stable despite low SRAM headroom.

## Design Principles Established

- Always test one subsystem at a time.
- Reduce RAM usage before adding features.
- Stream data; never load full files.
- Trust empirical hardware behavior over datasheets.

## Next Logical Extensions

- Add A/B buttons for file selection.
- Cache filenames per folder.
- Generalize folder selection (pages).
- Optional: migrate to RP2040 or ESP32 for more RAM.

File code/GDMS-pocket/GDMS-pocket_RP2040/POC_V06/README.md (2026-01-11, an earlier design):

# POC_V06 — Notes & Changes

This file documents the features and fixes added to the POC_V06 sketch.

## ✅ New features

- **Weighted CSV selection**
  - Lines can begin with an integer weight followed by a comma to increase selection probability:
    - Example: `3,Goblin` → Goblin has weight 3.
  - If no leading weight is present or the token is invalid, the line defaults to weight = 1.
  - Selection uses **single-pass weighted reservoir sampling** so files are read once and memory usage stays minimal (good for RP2040).

- **JSON recipe compatibility (V1)**
  - `.json` recipe files appear alongside `.csv` files and are executed when selected.
  - Recipes declare `parts[]` with `roll`, optional `label`, and optional probability `p` (0.0–1.0).
  - Relative (`roll": "names.csv"`) and root (`roll": "/items/treasure.csv"`) paths are supported.

## 🛠 Fixes & Robustness

- **Skip malformed / empty entries**
  - Lines that are empty or effectively a lone comma (e.g. `,` or `1,`) are now skipped and do not affect weights.
  - This prevents returning empty strings or stray commas as selection results.

- **Cross-folder recipe path normalization**
  - Recipe paths starting with `/data/...` (case-insensitive) or `/items/...` are normalized to the runtime `/DATA/...` root so cross-category references work reliably.

## ⚠️ Notes / Limitations

- Weight parsing expects an integer in the first token; non-integer tokens fall back to weight = 1.
- Non-positive parsed weights are clamped to `1`.
- Line buffer size is ~220 bytes; very long lines (>220 characters) may be truncated.
- Hidden files (leading `_`) are **not shown** in the UI but are available to recipes (intended behavior).

## 🧪 Testing suggestions

- Example test files are in `/data/Test/` (e.g. `encounter_gen.json`, `monsters.csv`, `_quant.csv`).
- On-device: select the `Test` category and run the `encounter_gen.json` recipe to verify output and rerolls.
- For debugging, enabling temporary Serial logging in `pickRandomCsvLine` can print skipped lines and parsed weights.

---

If you'd like, I can also add an `examples/` subfolder with sample weighted CSVs and a small serial test runner to demonstrate distributions. Let me know if you want that added. ✨

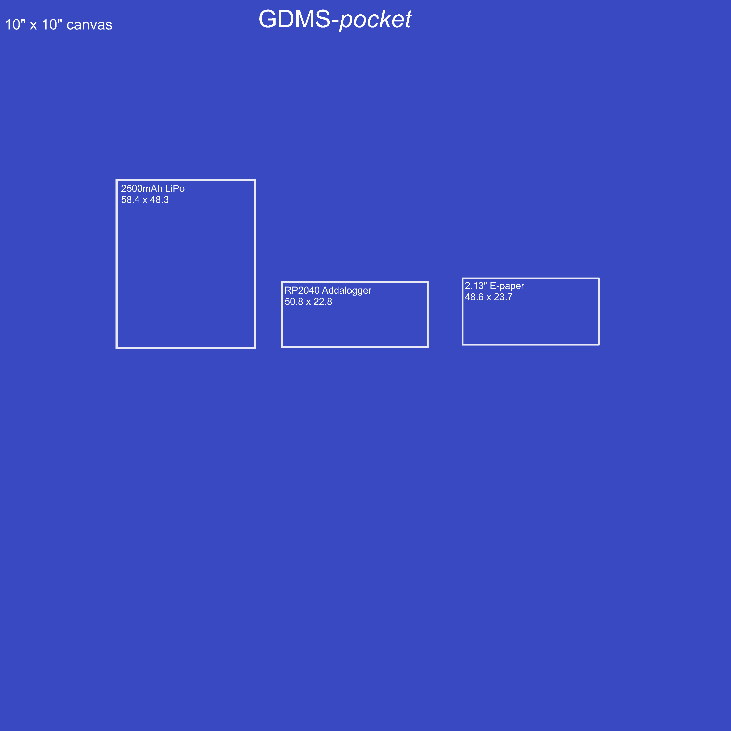
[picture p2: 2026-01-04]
LogsAndDocumentation/Blueprints/GDMS-pocket_Blueprint_251229.png

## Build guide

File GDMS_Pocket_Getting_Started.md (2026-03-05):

# GDMS:Pocket — Getting Started Guide

**Goblinoid Dungeon Mastering System**  
*A handheld random table roller for tabletop RPGs*

---

## What Is This?

GDMS:Pocket is a small handheld device that rolls on random tables for you at the table. Press a button, get a result. It runs entirely from a microSD card loaded with plain text files — no internet, no app, no phone required.

Out of the box it comes loaded with a set of tables for names, encounters, rooms, loot, and more. Everything on the card can be replaced or added to using any computer and a text editor.

---

## The Buttons

The device has four buttons. Their functions depend on which screen you're on.

```
          [ UP ]         [ B ]

         [ DOWN ]     [ A ]          
```

| Button | What it does |
|---|---|
| **UP / DOWN** | Move the cursor up or down through a list. Hold for fast scrolling. |
| **A** | Select the highlighted item, or re-roll a result you're already looking at. |
| **B** | Go back to the previous screen. |
| **A + B together** | Open the options menu from anywhere. |

---

## The Screens

### Category List (home screen)

When the device boots you'll see a list of categories — Names, Encounters, Rooms, and so on. These correspond to folders on the SD card. Scroll with UP/DOWN and press A to enter a category.

### File List

Inside a category you'll see a list of generators. Some are simple tables (single rolls), others are recipes that combine several tables into one result. Scroll and press A to roll.

### Result View

The rolled result is displayed here. If it's longer than the screen, scroll with UP/DOWN to read the rest. Press A to roll again on the same generator. Press B to go back to the file list.

### Options Menu

Hold A and B simultaneously from any screen to open options. Scroll with UP/DOWN, press A to cycle a setting's value. Press B to close. Settings are saved automatically and reload next time you power on.

| Setting | What it controls |
|---|---|
| Buzzer | Turn audio feedback on or off |
| Buz Vol | Loud or soft beeps |
| LED | Turn the indicator LED on or off |
| LED Pop | Flash the LED on button presses |
| LED Brt | LED brightness — Lo, Med, or Hi |
| Breathe | Speed of the LED breathing animation |
| Sleep | How long before the display turns off automatically. Press any button to wake it. |

### About Screen

Accessible from the bottom of the options menu. Shows the control reference and device information.

---

## The Battery Indicator

The small icon in the top-right corner of every screen shows the battery level.

| Icon | Meaning |
|---|---|
| Three bars | Full — plenty of charge |
| Two bars | OK — no rush |
| One bar | Low — charge soon |
| Empty, flashing | Critical — charge now |

The device runs on a rechargeable LiPo battery. Charge it using a USB-C cable. The small orange LED near the USB port will light while charging and go out when full.

---

## What's on the SD Card

The microSD card holds all the content the device displays. To access it, power the device off and remove the card from the slot on the underside of the board. Insert it into your computer using a card reader.

The card is organised like this:

```
/DATA/
  /names/
      fantasy-names.csv
      tavern-names.csv
  /encounters/
      wilderness.csv
      dungeon.csv
      npc.json
  /rooms/
      room.json
      _features.csv
      _hazards.csv
```

Each folder inside `/DATA` becomes a category on the device. The folder's name is what you see on screen. Files inside the folder are the generators you can roll on.

---

## Removing Default Content

To remove a category entirely, delete its folder from the card. To remove a single generator, delete the `.csv` or `.json` file. The device will not show entries that don't exist — there's nothing else to update or configure.

If you want to keep a file on the card but hide it from the device's UI (for example, a support table used by a recipe but not useful to roll on directly), rename it so it starts with an underscore: `_myfile.csv`. It will be invisible to the interface but still accessible internally.

---

## Adding Your Own Content

### Simple Table (CSV)

Create a plain text file with a `.csv` extension. Put it inside a category folder under `/DATA`. Each line becomes one possible result. That's it.

**Example — `/DATA/names/pirate-names.csv`:**

```
Barnacle Pete
One-Eyed Sal
The Drowned Captain
Mira of the Tides
Deckhand Corrigan
```

Any line editor will do — Notepad on Windows, TextEdit on Mac (save as plain text, not rich text), or any code editor.

**Rules for CSV files:**
- One result per line
- Blank lines are skipped automatically
- Lines starting with `#` or `//` are treated as comments and skipped
- File encoding should be UTF-8 (the default on all modern systems)

### Weighted Table

If you want some results to come up more often than others, add a number at the start of each line followed by a comma. Higher numbers mean higher probability.

```
3,Common sword
3,Shortbow
2,Crossbow
1,Hand axe
1,War hammer
```

In this example a common sword or shortbow is three times more likely than a war hammer. You can mix weighted and unweighted files freely — any line without a leading number is treated as weight 1.

### New Category

Create a new folder inside `/DATA` and add `.csv` or `.json` files inside it. The folder name is what appears on the device. Keep names short — the display is small and long names will be automatically truncated with `...`.

**Tips for folder names:**
- Aim for 12 characters or fewer for clean display
- Use hyphens instead of spaces if you need multi-word names (`wild-magic` not `wild magic`)
- Avoid special characters

---

## JSON Recipes (Advanced)

A recipe is a `.json` file that generates a multi-part result by chaining rolls from multiple CSV tables. This is what makes a generator that produces a full NPC profile — name, job, personality trait, secret — all in one roll.

### Basic Recipe Structure

```json
{
  "parts": [
    { "label": "Name",  "roll": "names.csv" },
    { "label": "Job",   "roll": "jobs.csv" },
    { "label": "Trait", "roll": "_traits.csv", "p": 0.75 }
  ]
}
```

Save this as `npc.json` inside a category folder. When selected, the device rolls each part in order and displays the combined result.

### Recipe Fields

**`roll`** — the CSV file to sample from. Can be a filename relative to the recipe's folder, or a path from `/DATA` for cross-category references:

```json
{ "roll": "names.csv" }
{ "roll": "/items/treasure.csv" }
```

**`label`** — optional text shown before the result on that line:

```
Name: Aldric Vane
Job: Gravedigger
```

**`p`** — optional probability from 0.0 to 1.0 that this part appears at all. Useful for optional details that shouldn't show up every time:

```json
{ "label": "Secret", "roll": "secrets.csv", "p": 0.40 }
```

A `p` of 0.40 means this line appears roughly 40% of rolls.

### Example: Full NPC Generator

File: `/DATA/npcs/npc.json`

```json
{
  "parts": [
    { "label": "Name",       "roll": "_names.csv" },
    { "label": "Occupation", "roll": "_jobs.csv" },
    { "label": "Trait",      "roll": "_traits.csv" },
    { "label": "Wants",      "roll": "_wants.csv",  "p": 0.8 },
    { "label": "Secret",     "roll": "_secrets.csv", "p": 0.5 }
  ]
}
```

The ingredient tables (`_names.csv`, `_jobs.csv`, etc.) are named with a leading underscore so they don't clutter the file list — only `npc.json` appears to the user.

### Format String (Optional)

For a single-line output style rather than labelled lines, add a `format` key using `{label}` placeholders:

```json
{
  "format": "{Name}, {Occupation} — {Trait}",
  "parts": [
    { "label": "Name",       "roll": "_names.csv" },
    { "label": "Occupation", "roll": "_jobs.csv" },
    { "label": "Trait",      "roll": "_traits.csv" }
  ]
}
```

This produces output like:

```
Aldric Vane, Gravedigger — Speaks only in proverbs
```

---

## Troubleshooting

**The device doesn't turn on.**  
Check that the battery is charged. Connect via USB-C and look for the orange charging LED near the port. If it lights, the battery was flat — give it 30–60 minutes before trying again.

**The screen is blank but the LED is breathing.**  
The device has entered sleep mode. Press any button to wake it. If you'd prefer a longer timeout or no timeout at all, adjust the Sleep setting in the options menu (A+B).

**A category or file I added isn't showing up.**  
Make sure the folder is directly inside `/DATA` with no intermediate folders. Make sure the file has a `.csv` or `.json` extension (not `.csv.txt`, which some systems add by default). If the filename starts with `_` it will be deliberately hidden — rename it without the underscore.

**The display shows "SD fail, retry..." on boot.**  
The SD card isn't being read. Re-seat the card and power cycle. If the problem persists, try reformatting the card as FAT32 on your computer and copying the content back.

**Results look garbled or CSV entries aren't rolling correctly.**  
Open the file in a plain text editor and check that it saved as UTF-8 without a BOM (Byte Order Mark). Some editors on Windows default to UTF-16 or add a BOM, which breaks line parsing. In Notepad, use File → Save As → Encoding: UTF-8.

**A JSON recipe shows "No selectable output."**  
This usually means one of the CSV files referenced in the recipe's `roll` paths couldn't be found. Check that the paths are correct, including capitalisation — the SD card filesystem is case-sensitive. Check that any cross-category paths start with `/` and reference folders that actually exist under `/DATA`.

---

## Tips

- Category and file names are displayed without their extensions. Name your files descriptively — `dungeon-rooms.csv` shows as `dungeon-rooms` on screen.
- You can have multiple recipes in the same category, each combining tables in different ways.
- Tables can be shared across categories using cross-category paths in recipes. A single `names.csv` can serve NPC generators, tavern generators, and ship generators all at once.
- The device saves your options settings automatically. You don't need to do anything special — just change a setting in the menu and it's stored.
- If you're playtesting new tables, add them to the card and roll through them to check for formatting issues, weird entries, or lines that are too long for the screen before your session.

---

*GDMS:Pocket by Alexander Sousa, 2026*

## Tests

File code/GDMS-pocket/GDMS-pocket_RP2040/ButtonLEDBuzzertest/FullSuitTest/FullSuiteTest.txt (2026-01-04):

// Written for the Adafruit RP2040 Adalogger feather in the Arduino programmgin language

#include <Wire.h>
#include <Adafruit_GFX.h>
#include <Adafruit_SSD1306.h>

// =================== PINS ===================
const uint8_t LED_PIN    = 11;   // your external LED on D11
const uint8_t BUZZER_PIN = 12;   // passive buzzer on D12

const uint8_t BTN_PINS[4]  = {5, 6, 9, 10};
const char*   BTN_NAMES[4] = {"D5", "D6", "D9", "D10"};

// =================== OLED ===================
#define SCREEN_WIDTH 128
#define SCREEN_HEIGHT 64
Adafruit_SSD1306 display(SCREEN_WIDTH, SCREEN_HEIGHT, &Wire, -1); // -1 = no reset pin

// =================== LED DIM ===================
const uint8_t LED_DIM = 30; // 0–255

// =================== BUTTONS ===================
bool wasPressed[4] = {false, false, false, false};
uint32_t lastPressMs[4] = {0, 0, 0, 0};
const uint16_t DEBOUNCE_MS = 40;

// =================== NON-BLOCKING LED BLINK ===================
bool ledBlinkOn = false;
uint32_t ledOffMs = 0;

// =================== NON-BLOCKING BUZZER ===================
bool buzOn = false;
uint32_t buzOffMs = 0;

void buzzerStart(uint16_t freq, uint16_t durMs) {
  tone(BUZZER_PIN, freq);
  buzOn = true;
  buzOffMs = millis() + durMs;
}

void buzzerUpdate(uint32_t now) {
  if (buzOn && (int32_t)(now - buzOffMs) >= 0) {
    noTone(BUZZER_PIN);
    buzOn = false;
  }
}

// =================== OLED UPDATE POLICY ===================
// Update OLED only when idle (no recent button activity)
uint32_t lastInputMs = 0;
uint32_t lastOledMs = 0;
const uint16_t OLED_PERIOD_MS = 300;      // at most ~3x/sec when idle
const uint16_t OLED_IDLE_AFTER_MS = 250;  // don't refresh OLED right after input

int lastPressedIdx = -1;

void drawOled(bool pressedNow[4], bool anyPressed) {
  display.clearDisplay();
  display.setTextSize(1);
  display.setTextColor(SSD1306_WHITE);

  display.setCursor(0, 0);
  display.print("GDMS Pocket Test");

  display.setCursor(0, 14);
  display.print("LED: ");
  display.print(anyPressed ? "ON " : "OFF");

  display.setCursor(0, 24);
  display.print("Last: ");
  if (lastPressedIdx >= 0) display.print(BTN_NAMES[lastPressedIdx]);
  else display.print("-");

  display.setCursor(0, 38);
  display.print("D5:");
  display.print(pressedNow[0] ? "D" : "-");
  display.print(" D6:");
  display.print(pressedNow[1] ? "D" : "-");

  display.setCursor(0, 48);
  display.print("D9:");
  display.print(pressedNow[2] ? "D" : "-");
  display.print(" D10:");
  display.print(pressedNow[3] ? "D" : "-");

  display.display();
}

void setup() {
  Serial.begin(115200);
  delay(200);

  pinMode(LED_PIN, OUTPUT);
  pinMode(BUZZER_PIN, OUTPUT);

  for (int i = 0; i < 4; i++) {
    pinMode(BTN_PINS[i], INPUT_PULLUP); // button to GND
  }

  Wire.begin();
  Wire.setClock(400000); // faster I2C helps OLED a lot

  if (!display.begin(SSD1306_SWITCHCAPVCC, 0x3C)) {
    Serial.println("SSD1306 init failed (addr 0x3C?)");
    while (1) delay(10);
  }

  display.clearDisplay();
  display.setTextSize(1);
  display.setTextColor(SSD1306_WHITE);
  display.setCursor(0, 0);
  display.print("Boot...");
  display.display();

  // short startup chirp
  buzzerStart(880, 40);
  delay(60);
  buzzerStart(1320, 40);

  lastInputMs = millis();
}

void loop() {
  uint32_t now = millis();
  buzzerUpdate(now);

  // end LED blink
  if (ledBlinkOn && (int32_t)(now - ledOffMs) >= 0) {
    analogWrite(LED_PIN, 0);
    ledBlinkOn = false;
  }

  // read buttons
  bool pressedNow[4];
  bool anyPressed = false;
  bool gotEvent = false;

  for (int i = 0; i < 4; i++) {
    bool curPressed = (digitalRead(BTN_PINS[i]) == LOW);
    pressedNow[i] = curPressed;
    if (curPressed) anyPressed = true;

    // pressed edge
    if (!wasPressed[i] && curPressed) {
      if (now - lastPressMs[i] >= DEBOUNCE_MS) {
        lastPressMs[i] = now;
        wasPressed[i] = true;

        gotEvent = true;
        lastInputMs = now;
        lastPressedIdx = i;

        // dim blink (non-blocking)
        analogWrite(LED_PIN, LED_DIM);
        ledBlinkOn = true;
        ledOffMs = now + 80;

        // beep (non-blocking)
        buzzerStart(880 + i * 200, 30);

        Serial.print(BTN_NAMES[i]);
        Serial.println(" PRESSED");
      }
    }

    // release edge (just update state)
    if (wasPressed[i] && !curPressed) {
      wasPressed[i] = false;
    }
  }

  // If you prefer LED ON while holding any button (instead of blink), use this:
  // analogWrite(LED_PIN, anyPressed ? LED_DIM : 0);

  // OLED update only when idle and throttled
  if ((now - lastOledMs >= OLED_PERIOD_MS) && (now - lastInputMs >= OLED_IDLE_AFTER_MS)) {
    lastOledMs = now;
    drawOled(pressedNow, anyPressed);
  }

  delay(1);
}

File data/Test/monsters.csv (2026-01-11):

1 | Centaur
1 | Ogre
1 | Troll
2 | Goblin
2 | Kobold
2 | Wolf
3 | Rat
1 | Dragon

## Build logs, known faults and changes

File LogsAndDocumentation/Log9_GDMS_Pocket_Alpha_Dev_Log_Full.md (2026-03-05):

# GDMS Pocket – Dev Log
## Alpha Development Arc: Logs 1–9
### Word Wrapping, Hold-Scroll, Looping Menus, LED Breathe & Pop, Options Menu, Sleep/Wake, Scrollbars, Battery Indicator

**Period:** January–March 2026  
**Author:** Alexander Sousa  
**Hardware:** Adafruit Feather RP2040 Adalogger + 1.5" SH1107 128×128 OLED (SPI)  
**Firmware at close of log:** GDMSpAlpha9.ino

---

## Overview

This log documents the full Alpha development arc of GDMS:Pocket, starting from the first working hardware bring-up (Alpha 1, covered in Log 8) through the battery voltage indicator and icon geometry work completed in Alpha 9. Each Alpha version is documented in the order it was developed, covering the problem that motivated the work, the approach taken, specific implementation decisions, issues encountered, and how they were resolved.

The codebase at the end of this arc is a stable, feature-complete handheld UI with word-aware text wrapping, hold-to-repeat navigation, looping menus, a full LED animation system, a settings menu with persistence, sleep/wake, scrollbars on all list views, and a live battery voltage indicator in the header.

---

## Alpha 1 — Hardware Bring-Up and SH1107 Display Fix

*(Documented in full in Log 8. Summarised here for continuity.)*

The first Alpha brought up all hardware peripherals on the Feather RP2040 Adalogger: the SH1107 OLED via software SPI, four momentary buttons, a passive buzzer, and an external LED. A full hardware validation sketch confirmed each peripheral was functional in isolation before integration.

The OLED required a library-level patch. The U8g2 SH1107 128×128 driver (`u8x8_d_sh1107.c`) sets `default_x_offset = 96` and `flipmode_x_offset = 96`, which causes a 32px horizontal wrap on the specific AliExpress panel used in this project. Content intended for the left edge appeared instead at the far right of the glass. The fix was to patch both offset values to `0` directly in the library source. This must be re-applied any time U8g2 is updated.

Final pin map established in this session and carried forward unchanged through Alpha 9:

| Peripheral | Pin(s) |
|---|---|
| OLED CLK | D13 |
| OLED DATA | D12 |
| OLED DC | D11 |
| OLED CS | D10 |
| OLED RST | D9 |
| Button UP | A1 |
| Button DOWN | A2 |
| Button A | A3 |
| Button B | 24 |
| Buzzer SIG | D6 |
| LED Anode | D25 |
| Battery divider tap | A0 |

---

## Alpha 2 — Word-Aware Line Wrapping

### Problem

When a rolled CSV result was displayed on screen, long entries were being cut at a fixed character count per line with no awareness of word boundaries. This produced mid-word breaks that were jarring to read — a result like "The innkeeper's daugh-\nter has a secret" rather than breaking cleanly between words.

A naive fix of just increasing the line length was not viable — the display is only 128px wide using a 6×12 font, giving approximately 20 usable characters per line before overlapping the scrollbar strip reserved on the right edge.

### Implementation

A custom word-aware line wrapper was written from scratch in Arduino-compatible C++ — no templates, no lambdas, no `std::string`. The constraints were tight: the RP2040 has 264kB of SRAM, and the wrapper needs to handle entries up to several hundred characters long without heap allocation in the render path.

The approach uses a statically allocated array of `WrapLine` structs (`wrapLines[MAX_WRAP_LINES]`, 64 entries max), each holding a null-terminated char buffer of `WRAP_CHARS + 1` bytes (21 bytes). This entire structure lives in static RAM, not on the call stack, and is reused on every redraw.

The wrapping algorithm (`buildWrappedLines()`) walks the source string a word at a time. It tracks the current line's accumulated length and a `lineStart` index into the source string. When a word would overflow the current line, the current line is emitted as a `WrapLine` by recording a `memcpy` slice into the buffer, and the word is re-evaluated on the fresh line.

Three edge cases required specific handling:

**1. Leading spaces at the start of a new line.** When a word causes a wrap and the next character is the inter-word space, that space would become the first character of the new line, producing an unintended indent. The algorithm eats this space explicitly before re-evaluating the next word.

**2. Words longer than the line width.** A word that cannot fit on any line regardless of wrapping (e.g. a very long URL or a run of characters with no spaces) is handled by a hyphenated hard-cut path. The word is broken into chunks of `WRAP_CHARS - 1` characters, each emitted with a trailing `-` character. The final chunk is emitted without a hyphen and left open for continuation by the following word.

**3. Explicit newlines in the source string.** Recipe outputs from the JSON system use `\n` to separate labelled parts (e.g. `"Name: Aldric\nJob: Gravedigger"`). The wrapper detects `\n` in the character scan and emits the current line immediately, then resets for the next line. This means multi-part recipe output wraps correctly at both the explicit newlines and within each part's own text.

The result is stored in `wrapLines[]` and `wrapLineCount`. The table draw function (`drawTable()`) iterates over this array to render visible lines, using `tableScrollLine` as the offset into the array.

---

## Alpha 3 — Hold-to-Repeat Scrolling

### Problem

With the word-aware wrapper producing multi-line results, navigating long entries required many individual UP/DOWN button presses. Holding a button did nothing — each press was treated as a single edge event. This made scrolling through a recipe output with six or eight wrapped lines tedious.

Additionally, scrolling through long category or file lists had the same problem — getting from the top to the bottom of a list with twenty entries required twenty individual presses.

### Implementation

The button handling loop in `loop()` was extended with a hold-to-repeat system. The key design constraint was that this had to work without blocking the main loop — no `delay()`, no polling loops. Everything is driven by `millis()` comparisons.

When a button transitions from not-pressed to pressed (falling edge), the existing debounce and edge-detection logic fires `onButtonPressed()` immediately as before. Two new timestamps are recorded: `holdStartMs[i]` (when the press was first confirmed) and `lastRepeatMs[i]` (when the last repeat event fired).

On every subsequent loop tick while the button remains held, the code checks:
- Has the button been held for longer than `HOLD_DELAY_MS` (500ms)? This is the intentional pause before repeat begins, preventing accidental holds from triggering repeats.
- Has `HOLD_REPEAT_MS` (100ms) elapsed since the last repeat fire?

If both conditions are true, `onButtonPressed()` is called again synthetically, exactly as if the button had been pressed again, and `lastRepeatMs[i]` is updated.

Critically, hold-to-repeat is **only enabled for BTN_UP and BTN_DOWN**. BTN_A and BTN_B are edge-only. This is intentional — holding A should not fire multiple rolls or multiple confirms, and holding B should not navigate back multiple screens. The `isRepeatBtn` flag gates the hold-repeat path specifically to the navigation buttons.

The parameters chosen:
- `HOLD_DELAY_MS = 500` — half a second of intentional hold before repeat starts. Feels deliberate without feeling sluggish.
- `HOLD_REPEAT_MS = 100` — ten repeat events per second. Fast enough to scroll a long list quickly, slow enough to maintain control at one-item-at-a-time granularity.

---

## Alpha 4 — Looping Menus

### Problem

Reaching the bottom of a category list or file list and pressing DOWN did nothing — the cursor stopped at the last item. Similarly, pressing UP at the top item stopped at item 0. This was the simplest possible boundary behaviour but it felt like hitting a wall. On a short list you'd frequently need to wrap — for example, to get from item 1 back to the last item quickly.

### Implementation

The cursor arithmetic in `onButtonPressed()` was changed from clamped to wrapping for both list modes.

For `MODE_CATS`:
```cpp
// Before (clamped):
if (b == BTN_UP && cursor > 0) cursor--;

// After (looping):
cursor = (cursor <= 0) ? (int16_t)(catCount - 1) : cursor - 1;
```

The same pattern applies to DOWN and to the file list in `MODE_FILES`. The `fileCursor` wraps analogously using `fileCount`.

The scroll window clamping (`scrollTop` tracking) was left unchanged — it continues to keep the selected item visible by sliding the viewport. Wrapping from item 0 to the last item causes `scrollTop` to jump to `catCount - rows`, correctly showing the end of the list. This required no special handling because the scroll clamping logic (`if (cursor < scrollTop) scrollTop = cursor`) already handles the case where the cursor moves above or below the current viewport.

The options menu cursor (`optCursor`) uses the same looping pattern, added when that menu was implemented in Alpha 6.

---

## Alpha 5 — LED Breathing and Pop

### Problem

The external LED on D25 was not doing anything useful. The original notes listed two desired behaviours: a slow breathing animation to indicate power-on state, and a brief bright flash ("pop") on each button press to give physical feedback. Both needed to run without blocking the main loop — a breathing animation driven by `delay()` would freeze the display and input handling.

### Implementation

**Triangle-wave breathing.** A sine wave would be more natural but requires floating-point math in every loop iteration, which is expensive on a microcontroller. A triangle wave — linear ramp up then linear ramp down — is computed from `millis()` with integer arithmetic only and produces a smooth enough fade for an LED.

```cpp
uint32_t t = (now + ledBreathOffset) % period;
if (t < period / 2) {
    val = (uint8_t)((uint32_t)breathMax * 2 * t / period);
} else {
    val = (uint8_t)((uint32_t)breathMax * 2 * (period - t) / period);
}
analogWrite(LED_PIN, val);
```

`period` is a runtime value pulled from `BREATH_PERIOD_TBL[]` (indexed by `breathSpeed` enum), so the breathing speed can be changed at runtime by the options menu without touching the animation code. `breathMax` similarly comes from `LED_BREATH_MAX_TBL[]` indexed by `ledBrightness`.

**Pop interrupt.** When a button is pressed, `ledPop()` is called. It captures the current phase of the breath cycle into `ledBreathOffset`, sets `ledPopActive = true`, writes full (or brightness-scaled) brightness immediately via `analogWrite`, and sets `ledPopEndMs` 100ms in the future.

In `ledUpdate()`, when `ledPopActive` is true, the breath calculation is skipped entirely — the LED holds at pop brightness until `ledPopEndMs` is reached. When the pop expires, `ledPopActive` is cleared and the animation resumes from the captured phase offset. This means the LED doesn't jerk back to wherever the breath wave happened to be — it picks up from the same point the cycle was at when the pop fired, producing a seamless transition back into breathing.

**Master switches.** `ledEnabled` is a boolean master switch that turns the entire LED off (breath + pop). When false, `ledUpdate()` immediately writes 0 to the LED and clears `ledPopActive`. `ledPopEnabled` independently controls whether pops fire while breathing continues — useful for someone who finds the flash distracting but wants the ambient breathing. Both are exposed in the options menu.

---

## Alpha 6 — A+B Combo Options Menu

### Problem

The device needed a settings menu but had only four buttons, all needed for navigation. Dedicating a button to "open menu" would sacrifice one of the four navigation inputs. The solution was to use a simultaneous button chord — pressing A and B together — as a meta-input to open the options screen from any mode.

### Implementation

**Chord detection.** The A+B combo is detected in `loop()` independently of the normal button edge-detection path. Both `BTN_A` and `BTN_B` GPIO states are read directly each tick. If both are LOW, a timer (`abComboArmMs`) starts. If both remain LOW for `AB_COMBO_MS` (80ms), the combo fires. This 80ms window requires both buttons to be held simultaneously for long enough to be intentional, while short enough to feel responsive.

`abComboFired` prevents the options screen from being opened repeatedly while the chord is held. It resets only when one or both buttons are released. The combo is also suppressed if already in `MODE_OPTIONS` (you can't open options from inside options).

**prevMode.** When the combo fires, the current `mode` is saved to `prevMode` before switching to `MODE_OPTIONS`. Pressing B inside the options menu restores `mode = prevMode`, returning to wherever the user was — categories, files, or result view — without losing their position.

**Options menu contents (Alpha 6 initial):**
- Buzzer on/off
- Buzzer volume (loud/soft)
- LED on/off
- LED pop on/off

Each option is displayed as `label    <value>` with the value right-aligned. Pressing A cycles the selected setting's value forward through its possible states. Settings took effect immediately on change; persistence to SD was added in Alpha 7.

**Buzzer volume as a software approximation.** The passive buzzer module used has no hardware volume control. The only software-accessible parameter is tone duration — shorter beeps are perceived as quieter because less energy is delivered to the buzzer membrane. `BUZ_VOL_SOFT` halves the requested duration before calling `tone()`. This is an imperfect approximation; the recommendation remains to add a ~1kΩ series resistor on the signal line for a true hardware volume reduction, but the software approach is a usable interim solution.

---

## Alpha 7 — Sleep/Wake, Scrollbars, and About Screen

### Sleep and Wake

The device needed a display-off idle timeout to preserve battery when left on a table between rolls. The implementation follows the same non-blocking `millis()` pattern as the LED and buzzer.

`lastActivityMs` is updated every time `onButtonPressed()` is called — not `lastInputMs`, which tracks the last input for OLED throttle purposes, but a separate timestamp specifically for the sleep system. This distinction matters because the OLED throttle idle timer is much shorter (a few milliseconds) than the sleep timeout (several minutes), and conflating them would cause incorrect behavior.

In `loop()`, every tick checks whether `now - lastActivityMs >= SLEEP_TIMEOUT_TBL[sleepTimeout]`. If the device is not already sleeping and the timeout has elapsed, `deviceSleeping` is set to true and the display is blanked by rendering a page-buffer cycle with no drawing commands — this produces a full black frame rather than leaving the last image static on the OLED.

Wake is handled inside `onButtonPressed()`. The first line after updating timestamps checks `deviceSleeping`. If true, it clears the flag, calls `uiRedraw()` to restore the display, and then continues processing the button that caused the wake. This means the wake button is not consumed by the wake action — it performs its intended function (UP/DOWN/A/B) as well as waking the display. This felt more responsive than requiring an extra press just to wake.

Four timeout values are available via the options menu: 5 minutes, 10 minutes, 30 minutes, and Never. The "Never" case is implemented by storing `0` in `SLEEP_TIMEOUT_TBL[SLEEP_NEVER]` and checking `tmo > 0` before comparing to `lastActivityMs`, so a zero timeout simply never triggers.

### Scrollbars

Long lists — more categories than fit on one screen, more files than fit on one screen, result text longer than the visible area — needed a visual indicator of scroll position and remaining content.

A shared `drawListScrollbar()` function was written to serve the category list, the file list, and the options menu (all of which are indexed, fixed-size lists). A separate but structurally identical scrollbar is drawn inline in `drawTable()` for the result text view (which uses wrapped-line count rather than item index).

**Scrollbar anatomy.** The scrollbar is a 3px wide vertical strip at the right edge of the display (x=125..127):
- A filled triangle at the top pointing up, indicating scroll-up is available. Hollow (outline only) when already at the top.
- A filled triangle at the bottom pointing down. Hollow when at the bottom.
- A thin centre line (1px `drawVLine`) connecting the two triangle bases — the track.
- A filled rectangle (the thumb) positioned on the track proportionally to the current scroll position.

Thumb height is proportional to `visibleRows / totalItems`, clamped to a minimum of 3px so it remains visible even with very long lists. Thumb position is scaled linearly: `thumbY = TRK_TOP + (thumbRange * scrollTop / maxScroll)`.

The scrollbar is only rendered when the list is longer than the visible area — if all items fit on screen, no scrollbar is drawn and that column of pixels is available for content.

**Result text scrollbar.** The table view scrollbar uses the same triangle-track-thumb geometry but parameterised on `wrapLineCount` (total wrapped lines) and `maxLinesOnScreen` (how many lines fit in the text area below the header). This scrollbar is unconditionally positioned at x=125..127, which is why the word wrapper uses `WRAP_CHARS = 20` — reserving the rightmost 6px column for the scrollbar strip even when the content is short.

### About Screen

A fifth UI mode (`MODE_ABOUT`) was added, accessible from the bottom row of the options menu. The About screen displays a brief description of the device, the author name, year, and a compact controls reference (which buttons do what). Pressing B from About returns to the options menu rather than to `prevMode`, since About is a sub-page of Options rather than a top-level destination.

### Settings Added in Alpha 7

The options menu was expanded with three additional entries:
- **LED Brightness:** cycles through Low (breathMax=20, popBrightness=25), Med (80/128), High (180/255). Both breath ceiling and pop peak are read from lookup tables indexed by the `LedBright` enum.
- **Breath Speed:** cycles through Fast (500ms period), Med (3000ms), Slow (10000ms). The period is read from `BREATH_PERIOD_TBL[]` each animation tick, so changing the speed takes effect immediately on the next `ledUpdate()` call.
- **Sleep Timeout:** cycles through 5 min, 10 min, 30 min, Never.

### Settings Persistence

All settings were given persistence to SD in Alpha 7. `saveSettings()` writes a simple `key=value\n` text file to `/DATA/settings.cfg` immediately whenever any setting is changed. `loadSettings()` reads it on boot. Unknown keys are silently ignored for forward compatibility.

The format is intentionally human-readable and simple — no binary, no JSON, no checksum. The file is small enough that the write is instantaneous from the user's perspective.

---

## Alpha 8 — Scrollbar on Category List, BAT Placeholder

Two remaining list views that lacked scrollbars were addressed: the category list (`MODE_CATS`) and the options menu. Both now call `drawListScrollbar()` with their respective item count, visible row count, and scroll offset. This completed scrollbar coverage across all list-type views.

A static `"BAT"` text label was added to the top-right corner of the header as a placeholder, marking the intended position of the future battery indicator. This was explicitly a temporary placeholder — not functional, just a spatial reservation while the battery monitor circuit and firmware were designed.

---

## Alpha 9 — Battery Voltage Monitor and Header Truncation

### Hardware: External Voltage Divider

The Feather RP2040 Adalogger does not include a built-in battery voltage monitor circuit. This is documented by Adafruit and is a deliberate board design decision given the RP2040's limited analog GPIO count. An external resistor divider is required:

```
VBAT ──[ 100kΩ ]──┬──[ 100kΩ ]── GND
                  │
                  └── A0
```

Two equal resistors produce exactly half the battery voltage at the center tap. The RP2040 ADC reference is 3.3V; a fully charged LiPo at 4.2V would exceed this if read directly and potentially damage the pin. Halving gives a maximum of 2.1V at A0, safely within range. The firmware doubles the ADC result to recover the true voltage.

A0 is free for this purpose. A stale comment in the source had incorrectly listed A0 as the B button pin — a holdover from an earlier hardware revision. The actual B button is on pin 24. The comment was corrected in this session.

### ADC Sampling

The RP2040 ADC is functional but noisy. `sampleBattery()` takes 8 readings with a 1ms delay between each and averages them. ADC resolution is explicitly set to 12-bit (0–4095) at the start of each call. The conversion to voltage:

```cpp
float raw = sum / 8.0f;
float vA0 = (raw / 4095.0f) * 3.3f;
battVoltage = vA0 * 2.0f;
```

Sampling occurs on a 5-second non-blocking timer in `loop()`, consistent with the existing non-blocking patterns for LED and buzzer. An initial sample is taken during `setup()` before `uiRedraw()` so the first rendered frame shows a real reading rather than the optimistic default of 4.2V.

### Voltage Thresholds and BattLevel Enum

Four charge tiers were defined. The `BattLevel` enum values are assigned so that the numeric value equals the number of bars to draw — this eliminates any translation step in the drawing code:

| Enum | Value | Bars drawn | Voltage |
|---|---|---|---|
| `BATT_CRIT` | 0 | 0 (empty, flashing) | < 3.5V |
| `BATT_LOW` | 1 | 1 bar | ≥ 3.5V |
| `BATT_OK` | 2 | 2 bars | ≥ 3.7V |
| `BATT_FULL` | 3 | 3 bars | ≥ 4.0V |

The `fillSegs = (int)lvl` assignment in the drawing function requires no case statement or lookup table.

### Battery Icon Design and Geometry — Iteration 1

The initial icon was designed with 4 fill bars to match the 4 charge tiers, body width `BODY_W=18`, `ICON_X=108`. The bars were 3px wide, 1px gaps, left inner pad of 1px. This fit the interior cleanly:

```
4 bars × 3px + 3 gaps × 1px + 1px left pad + 1px right pad = 16px interior
Body interior = 18 - 2 (outline) = 16px ✓
```

When the design was revised to 3 bars (FULL=3, OK=2, LOW=1, CRIT=0/empty/flash) the bar count was reduced from 4 to 3 without resizing the body, leaving a 4px dead space on the right side of the interior. The rightmost bar appeared to have unequal padding compared to its neighbours.

Additionally, a geometry error in `SEG_X0` meant the rightmost bar's right edge landed exactly at the body's inner right wall (x=124 in an 18px body at x=108), producing zero clearance between the bar and the outline — the bar appeared visually merged with the body wall.

### Battery Icon Design — Iteration 2 (Final)

Both issues were corrected by properly sizing the body for 3 bars with 1px clearance on all four sides of every bar:

```
Required interior = 1px left pad + 3×3px bars + 2×1px gaps + 1px right pad = 13px
BODY_W = 13px interior + 2px outline = 15px
ICON_X = 128 - 15px body - 2px nub - 1px gap from edge = 111
```

Verified bar positions:

| Bar | Left edge | Right edge | Right clearance to inner wall |
|-----|---|---|---|
| 0 | x=113 | x=115 | 9px |
| 1 | x=117 | x=119 | 5px |
| 2 | x=121 | x=123 | 1px |

Inner right wall at x=124. Every bar has exactly 1px clearance on all four sides.

The nub sits at x=126..127, flush with the display's right edge.

### Critical Flash Animation

At `BATT_CRIT`, the icon alternates between a normal state (empty body outline, no bars) and an inverted state (white flood-fill of body and nub, with bar positions punched back to black using `setDrawColor(0)`) on a 500ms period derived from `(millis() / 500) % 2`. No persistent blink state variable is needed — the current frame's appearance is computed entirely from the current `millis()` value on each redraw.

### Header Title Truncation

The static `"BAT"` label was replaced by the icon. The `drawHeader()` function was updated to measure the title string's rendered pixel width using `u8g2.getStrWidth()` and compare it to the available space (`MAX_TITLE_W = 109px`, being `ICON_X=111` minus a 2px gap). If the title exceeds this budget, characters are removed one at a time until `title + "..."` fits, then `"..."` is appended.

Pixel measurement via `getStrWidth()` is used rather than a character-count heuristic because `u8g2_font_8x13_tf` is not strictly monospaced — narrower glyphs would allow more characters than a fixed 8px-per-character estimate. Measuring directly is always accurate regardless of font metrics.

---

## Current Known-Good State at Alpha 9

- All four buttons debounced and functional; UP/DOWN have hold-to-repeat; A/B are edge-only
- Looping navigation in all list modes
- Word-aware wrapping with hyphenation for oversized words, explicit newline support
- LED breathing (triangle wave, configurable speed and brightness), pop interrupt on button press
- Passive buzzer feedback, per-button distinct frequencies, configurable volume and master on/off
- A+B chord opens options from any mode; B closes and returns to previous mode
- Options menu: 7 configurable settings + About entry, all persisted to SD immediately on change
- Sleep/wake: configurable timeout, blanked display, any button wakes and processes simultaneously
- Scrollbars on all list views (categories, files, options) and result text view
- Live battery voltage indicator in header: 3-bar icon, 5-second sampling, critical flash
- Header title truncation protects battery icon from overflow

---

## Known Issues and Notes for Next Session

- **USB reads as "full":** When powered via USB-C, the BAT pin reflects the regulated USB supply rather than a LiPo cell. The battery icon will show FULL. No software-reliable USB detection is available on this board without additional hardware. Accepted behaviour.
- **Bar orientation:** Current bars fill left-to-right (leftmost bar is the last one remaining as battery drains). Right-to-left fill (bars drain from left, only right bar remains at LOW) may be more intuitive and is worth evaluating.
- **Battery voltage in About screen:** Displaying the raw measured voltage in the About screen would be useful for field calibration without a serial monitor.
- **Options menu `optScrollTop` is `static` inside `drawOptions()`:** This works correctly but is slightly unusual — it means the options scroll position persists across visits to the menu. Worth making it a proper file-scope variable for clarity.
- **`PIN_LED` macro collision warning:** The RP2040 Arduino core defines `PIN_LED` as a macro. The sketch uses `LED_PIN` to avoid collision, but this should be noted in any future code review.

---

**End of Log — Alpha 9**  
*Alexander Sousa, March 2026*

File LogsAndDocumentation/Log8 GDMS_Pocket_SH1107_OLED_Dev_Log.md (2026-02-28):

# GDMS Pocket – Dev Log  
## SH1107 1.5" OLED Bring-Up, Pin Mapping, Hardware Validation, JSON recipe functions, _file.ext ignore behavior.

### Date
January 2026

---

## Goal of This Session
Bring up a newly received **1.5" SH1107 OLED (SPI)** on a **Feather RP2040 Adalogger**, resolve display alignment issues, finalize a clean pin map for all peripherals (OLED, buttons, LED, buzzer), and validate everything with a single hardware test sketch.

---

## Hardware Used
- Adafruit Feather RP2040 Adalogger
- 1.5" OLED, controller marked **SH1107**, SPI interface (AliExpress module)
- 4 momentary buttons (active-low)
- Passive buzzer (3-pin module)
- Single indicator LED + resistor

---

## OLED Bring-Up and Debugging

### Initial Issues
- Screen powered but showed:
  - shifted / wrapped content
  - apparent ~32px horizontal offset
- U8g2 rotation flags and page buffer settings did **not** resolve the issue.

### Root Cause Identified
The issue was traced to the **U8g2 SH1107 128×128 driver** (`u8x8_d_sh1107.c`).

In the `u8x8_sh1107_128x128_display_info` struct, the library defines:

```c
default_x_offset = 96
flipmode_x_offset = 96
```

This causes horizontal **wraparound addressing** on some SH1107 panels (columns 0–31 appear at the far right of the display).

### Final Fix (Driver-Level)
The OLED panel used in this project expects a **true column 0 origin**.

**Library patch applied:**
```diff
- default_x_offset = 96
- flipmode_x_offset = 96
+ default_x_offset = 0
+ flipmode_x_offset = 0
```

After this change:
- `(0,0)` maps correctly to the top-left of the glass
- `drawFrame(0,0,128,128)` renders correctly
- No application-level coordinate hacks required

⚠️ **Important:** This change lives inside the U8g2 library.  
Documented in repo so it can be re-applied if the library is updated.

---

## OLED Configuration (Final, Working)

- Library: **U8g2**
- Constructor used:
```cpp
U8G2_SH1107_128X128_1_4W_SW_SPI
```

- Software SPI (intentionally avoids SPI conflicts with SD card)

### OLED Pin Mapping
| OLED | Feather RP2040 |
|----|----|
| VCC | 3V3 |
| GND | GND |
| SCL (CLK) | D13 |
| SDA (DATA) | D12 |
| DC | D11 |
| CS | D10 |
| RST | D9 |

---

## Final Pin Map (All Components)

### Buttons (Active-Low, INPUT_PULLUP)
Buttons are wired **pin → GND**.

| Button | Pin |
|---|----|
| Up | A1 |
| Down | A2 |
| A | A3 |
| B | 24 |

### Buzzer
- Passive buzzer
- PWM/tone capable

| Signal | Pin |
|---|----|
| SIG | D5 |
| VCC | 3V3 |
| GND | GND |

### LED
| Connection | Pin |
|---|----|
| Anode (via resistor) | D24 |
| Cathode | GND |

⚠️ Note: `PIN_LED` is defined as a macro in the RP2040 core.  
Do **not** use `PIN_LED` as a variable name in sketches.

---

## Validation Sketch
A single minimal test sketch was written and verified that:

- OLED initializes and renders text correctly
- All four buttons register reliably
- LED turns on when any button is pressed
- Buzzer emits distinct tones per button

This sketch serves as:
- a wiring validation tool
- a future regression test for hardware changes

---

## Current Known-Good State
- OLED mapping is correct and stable
- All pins are finalized and non-conflicting
- SD card SPI remains unused and unaffected
- Ready to:
  - switch OLED to `_F_` buffer mode (full framebuffer)
  - integrate OLED + input handling back into `POC_V04`
  - formalize pin definitions in a shared `pins.h`

---

## Next Logical Steps
1. Create `pins.h` reflecting the finalized pin map
2. Convert OLED constructor to `_F_` buffer on RP2040
3. Merge U8g2 rendering into GDMS UI code
4. Restore SD card functionality and test coexistence

---

**End of log**

## Log 8 Addendum – JSON Recipes, UI Refinements, and Audio Tuning  
**Date:** 2026  
**Author:** Alexander Sousa  

This addendum documents work completed after the initial Log 8 entry, focused on restoring and extending functionality following a partial code recovery, as well as refining UI and hardware feedback for the 128×128 OLED build.

---

### 1. JSON Recipe System (V1 Re-Integration)

The JSON “recipe” system was re-implemented after recovering a near-latest branch. The intent of this system is to allow higher-level generators (e.g. NPCs, rooms) to chain together multiple random table rolls into a single output.

**Key features implemented:**
- `.json` files are now treated as selectable generators alongside `.csv` tables.
- Files prefixed with `_` are hidden from the UI but remain accessible to recipes (e.g. `_icon.bin`, `_internal.csv`).
- JSON recipes define a `parts[]` array, each part specifying:
  - `roll`: a CSV path to sample from
  - `label` (optional): prepended to the result
  - `p` (optional): probability (0.0–1.0) that the part is included
- Recipes may reference:
  - Local files (relative to the recipe’s folder)
  - Cross-category files using `/DATA`-rooted paths (e.g. `/items/treasure.csv`)

**Runtime behavior:**
- Selecting a `.json` file runs the recipe and displays the composed output in the same table view as CSVs.
- Rerolling (`A` in table view) correctly re-executes the recipe rather than sampling raw JSON lines.

This establishes a stable **V1 recipe system** suitable for NPC, room, and encounter generators.

---

### 2. Input Handling Fixes (CSV vs JSON)

A critical fix was made to ensure consistent behavior between:
- Initial selection of a file (`MODE_FILES`)
- Rerolling while viewing results (`MODE_TABLE`)

Both code paths now branch explicitly based on file extension:
- `.csv` → `pickRandomCsvLine()`
- `.json` → `runJsonRecipeV1()`

This prevents erroneous behavior where rerolls on JSON generators would previously display raw JSON keys.

---

### 3. UI Layout Updates for 128×128 OLED

With the transition from a 0.96″ display to a 1.5″ 128×128 OLED:

- **Header text** was upgraded to a larger font for stronger visual identity.
- **Body text font and wrapping were intentionally left unchanged** to preserve density and readability.
- Vertical spacing was adjusted so content starts closer to the header divider, reclaiming usable screen space without risking overlap.
- Category list, file list, and table view now share consistent vertical layout assumptions.

These changes improve readability while keeping rendering logic stable.

---

### 4. Startup Splash Screen

A dedicated splash screen was added to display on boot for ~2 seconds before SD initialization and UI startup.

**Displayed text:**
GOBLINOID
DUNGEON
MASTERING
SYSTEM

-Alexander Sousa
2026

This establishes device identity and provides a clean, intentional startup experience.

---

### 5. Buzzer Volume Mitigation

The passive buzzer was identified as overly loud when driven directly via `tone()`.

**Mitigations discussed and partially implemented:**
- Reduced beep duration for UI feedback.
- Recommended hardware fix: series resistor (≈1 kΩ) on the buzzer signal line.
- Optional RC filtering discussed for further softening if desired.

This brings audio feedback more in line with a “quiet handheld tool” rather than an alarm-like device.

---

### 6. Future Considerations (Not Yet Implemented)

- Per-category icons loaded from SD (e.g. `_icon.bin` in each folder), rendered as 1-bit bitmaps.
- JSON recipes invoking other JSON recipes (nested generators).
- User-editable settings and saveable outputs.
- Optional migration from `StaticJsonDocument` to `JsonDocument` to align with newer ArduinoJson APIs.

---

**Status:**  
The recovered codebase is now functionally equivalent (and in some areas improved) relative to the original pre-loss state, with JSON recipes, UI scaling, and startup identity fully restored.

# GDMS-pocket JSON Recipe Conventions (V1)

## Purpose
A **recipe** is a `.json` file that generates a multi-line output by chaining together one or more random rolls from CSV tables.

Recipes appear in the UI alongside CSV files and can be selected like any other generator.

---

## File placement and visibility

### Category folders
All content lives under:

```
/DATA/<CATEGORY>/
```

A category folder can contain:
- visible CSV tables (`names.csv`)
- visible recipes (`npc.json`)
- **hidden support tables and assets** prefixed with `_` (`_traits.csv`, `_icon.bin`)

### Hidden files
Any file beginning with `_` is:
- **not shown in the UI file list**
- still accessible to recipes via `"roll"` paths

This allows “ingredient tables” and internal assets to be hidden from the user-facing interface.

---

## Recipe JSON structure

### Required structure
A V1 recipe is a JSON object containing:

- `parts`: an array of roll steps

```json
{
  "parts": [
    { "label": "Name", "roll": "names.csv" },
    { "label": "Goal", "roll": "_goals.csv", "p": 0.8 }
  ]
}
```

---

### `parts[]` entries

Each part is an object with the following fields:

#### `roll` (required)
Path to a CSV file that the recipe will roll on.

- **Relative path** (local to the recipe folder):
  ```json
  "roll": "names.csv"
  ```

- **Cross-category path** (rooted under `/DATA`):
  ```json
  "roll": "/items/treasure.csv"
  ```

---

#### `label` (optional)
Text prefix shown before the rolled result.

If present:
```
Label: <rolled line>
```

If omitted, the rolled line is printed alone.

---

#### `p` (optional)
Probability that this part appears in the output.

- Range: `0.0` to `1.0`
- Default: `1.0` (always included)

Examples:
- `1.0` → always included
- `0.25` → included ~25% of the time
- `0.0` → never included (useful for testing)

---

## Output format (V1)

Recipe output is a **multi-line string**.
Each included part contributes exactly one line, in order.

Example output:

```
Name: Joryn Kettle
Job: Dockhand
Trait: Always humming
```

Notes:
- Parts are processed top to bottom.
- Failed rolls are silently skipped.
- If no parts produce output, the UI displays:
  ```
  No selectable output.
  ```

---

## CSV expectations (V1)

Recipes roll from CSV files using simple random line selection.

- Empty lines are skipped
- Lines beginning with `#` or `//` are treated as comments
- No weighting or column parsing is performed in V1

---

## Naming conventions

Recommended patterns:

### Visible generators
- `npc.json`
- `room.json`
- `encounter.json`

### Hidden ingredient tables
- `_egress.csv`
- `_rumors.csv`
- `_gods.csv`

### Icons (future / optional)
- `_icon.bin` (32×32 monochrome bitmap)

---

## Example: Cross-folder room generator

If stored at `/DATA/room/room.json`:

```json
{
  "parts": [
    { "label": "Size", "roll": "size.csv" },
    { "label": "Shape", "roll": "shape.csv" },
    { "label": "Graffiti", "roll": "graffiti.csv", "p": 0.35 },
    { "label": "Trap", "roll": "/traps/traps.csv", "p": 0.20 },
    { "label": "Treasure", "roll": "/items/treasure.csv", "p": 0.25 },
    { "label": "Junk", "roll": "/items/junk.csv", "p": 0.40 }
  ]
}
```

---

## Reserved keys (forward compatibility)

These keys are reserved for future versions and may be included safely:

- `title` (string): display name override
- `type` (string): generator category (e.g. `npc`, `room`)
- `version` (number): recipe schema version

Example:

```json
{
  "title": "NPC Generator",
  "type": "npc",
  "version": 1,
  "parts": [
    { "label": "Name", "roll": "names.csv" }
  ]
}
```

---

## Planned V2 Extensions

- Recipes that invoke other recipes
- Weighted CSV support
- Formatting templates (single-line summaries)
- Grouped / conditional parts

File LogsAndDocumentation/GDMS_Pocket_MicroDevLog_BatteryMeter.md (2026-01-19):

# Micro Dev Log — Battery Meter Test (RP2040 Adalogger)

**Date:** January 2026  
**Project:** GDMS‑Pocket  
**Focus:** External battery voltage sensing + OLED display validation

---

## Goal

Create a **minimal, isolated test sketch** to validate:
- External LiPo battery voltage sensing via a **100kΩ / 100kΩ voltage divider**
- Stable ADC readings on the **RP2040 Adalogger**
- Correct display of **battery voltage and percentage** on the **1.5” SH1107 SPI OLED**
- Use of the **same OLED library stack (U8g2)** and pin mapping as the main project

This test intentionally excluded:
- SD card
- Buttons
- Buzzer
- UI state machine

The goal was confidence and clarity, not integration.

---

## Hardware Setup

### Battery Meter
- External voltage divider:
  - `BAT → 100kΩ → A0 → 100kΩ → GND`
- A0 reads **VBAT / 2**
- Divider current ≈ **21 µA @ 4.2 V** (acceptable for this device)

### OLED (SPI, Software SPI via U8g2)

OLED header (left → right):
`RST, CS, DC, SDA, SCL, GND, VCC`

Wiring:
- RST → D9  
- CS  → D10  
- DC  → D11  
- SDA → D12  
- SCL → D13  
- VCC → 3.3V  
- GND → GND  

Display driver:
- **SH1107 128×128**
- **U8g2 software SPI constructor**
- Page buffer (`_1_`) for low RAM use

---

## Software Stack

- **Library:** U8g2  
- **Constructor:**  
  `U8G2_SH1107_128X128_1_4W_SW_SPI`
- **ADC:** 12‑bit (`analogReadResolution(12)`)

### Battery Math

- ADC range: `0–4095`
- Reference voltage: `~3.3 V`
- Divider compensation: `×2.0`

Voltage:
```
VBAT = (raw / 4095.0) * 3.3 * 2.0
```

Percentage:
- Clamped range: **3.30 V → 0%**, **4.20 V → 100%**
- Non‑linear curve (`x^1.7`) to better match LiPo discharge behavior
- Exponential moving average to reduce jitter

---

## Test Result

✅ OLED initialized correctly using U8g2 + SW SPI  
✅ Battery voltage displayed correctly (stable, realistic values)  
✅ Percentage mapping behaved sensibly  
✅ No visible flicker or ADC noise after smoothing  
✅ Pin mapping confirmed safe and repeatable  

This validated:
- External divider approach
- Use of **A0** for battery sensing
- Continued use of **U8g2** for all OLED work
- Readiness to integrate battery indicator into main UI

---

## Design Decisions Locked In

- Battery sensing will use **external 100kΩ / 100kΩ divider**
- **A0** reserved exclusively for battery measurement
- OLED remains on **software SPI via U8g2**
- Battery % logic is suitable for header/UI integration
- Roll counter UI element can safely be replaced by battery indicator

---

## Next Steps

- Integrate battery reading into main GDMS‑Pocket UI
- Replace top‑right roll counter with:
  - Battery percentage text, or
  - Small battery icon + percent
- Optionally add:
  - Low‑battery warning threshold
  - Icon blink or chirp behavior

---

**Status:** ✅ Battery meter subsystem validated and ready for integration

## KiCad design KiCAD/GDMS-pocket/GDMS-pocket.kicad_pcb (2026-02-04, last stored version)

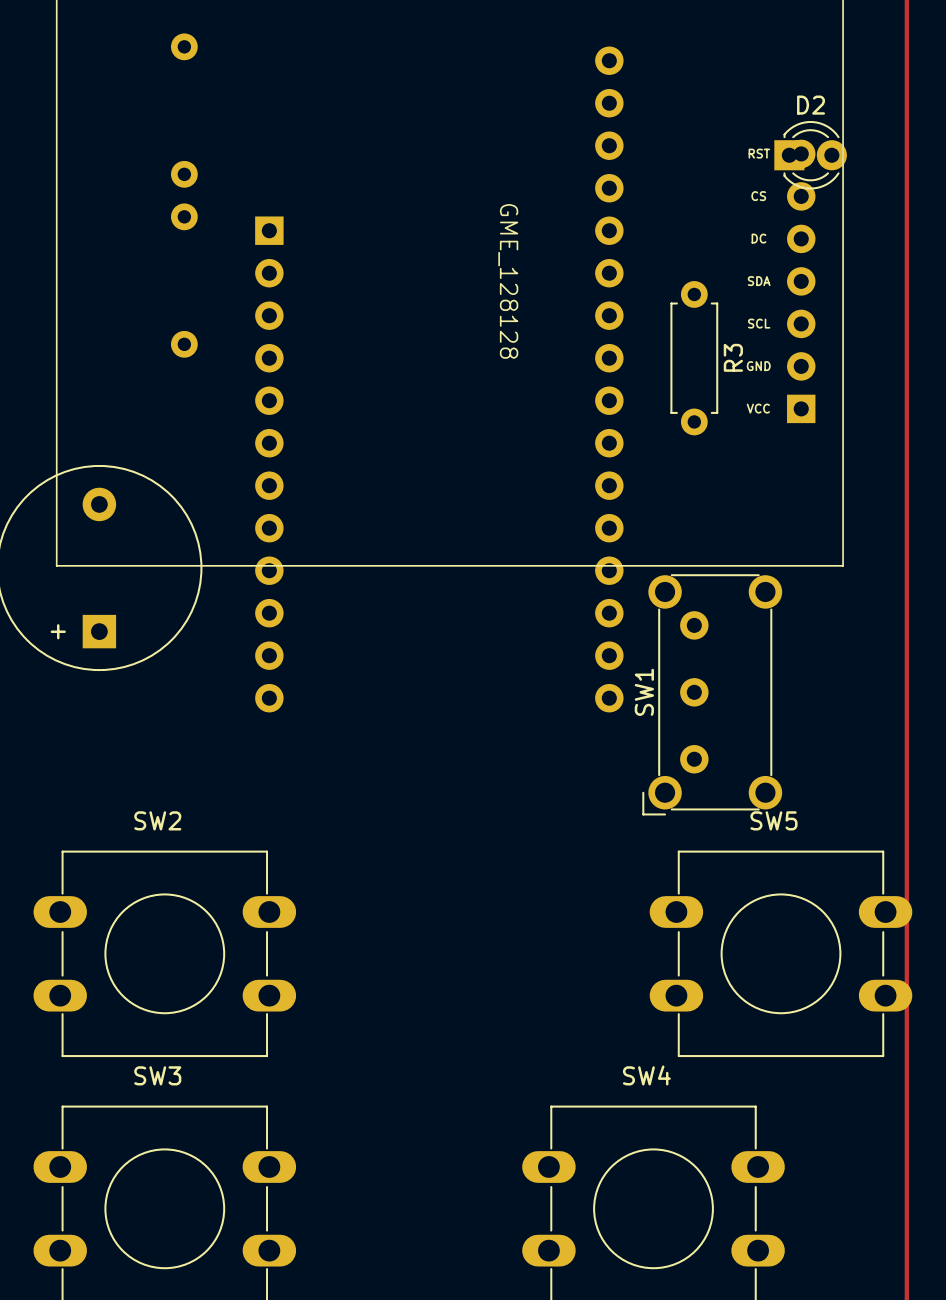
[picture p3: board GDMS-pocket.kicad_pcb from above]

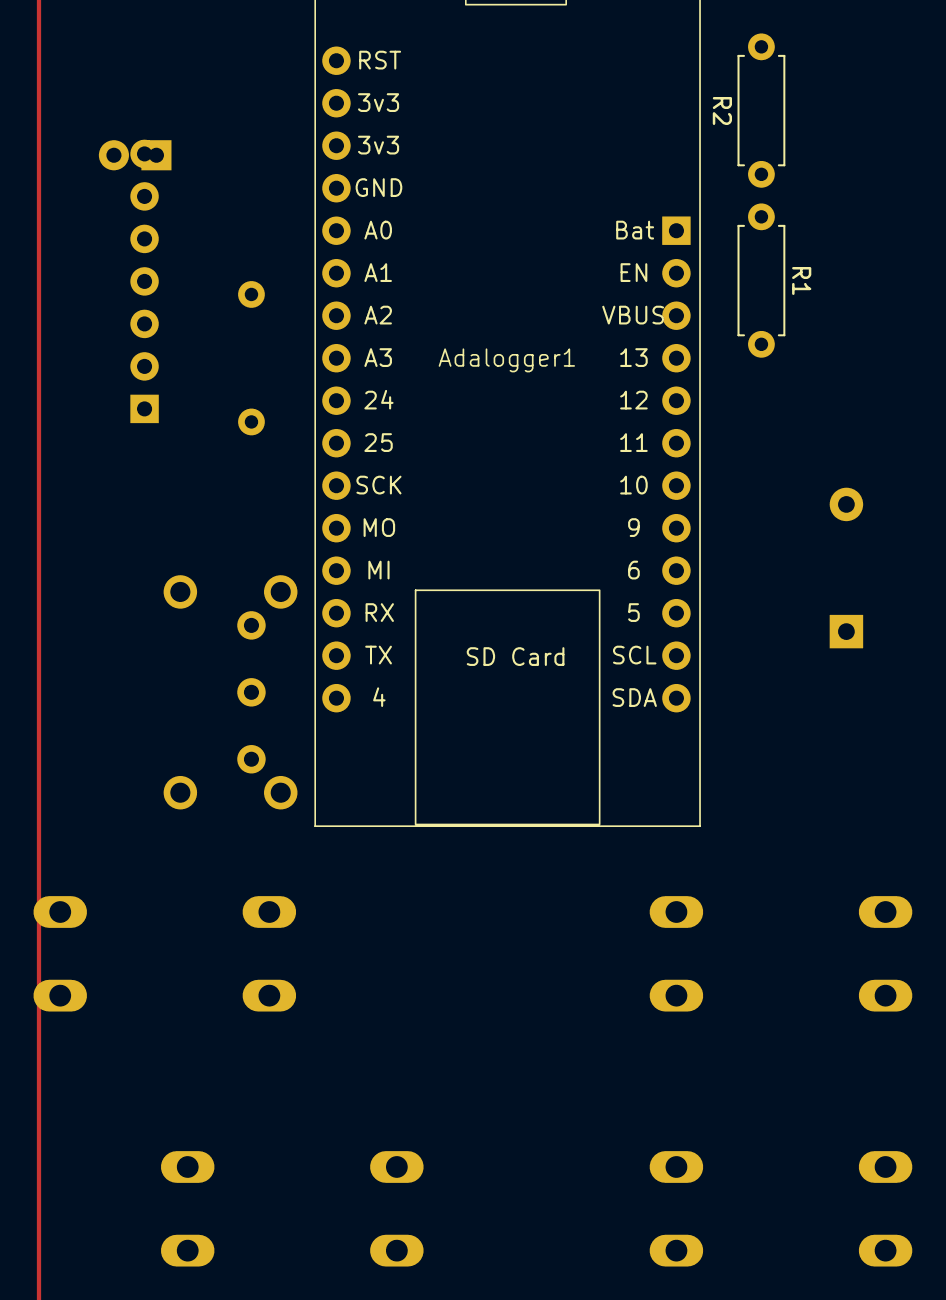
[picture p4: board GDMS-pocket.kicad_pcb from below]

Board: 2 copper layers, 12 parts (3 on the bottom side), 17 nets, no tracks yet.

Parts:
Adalogger1: Adafruit Feather Adalogger RP2040; Adafruit_Feather_Adalogger_RP2040
BZ1: Buzzer; Buzzer_12x9.5RM7.6
D2: LED; LED_D3.0mm
GME_128128: SH1107; 128128_SPI_SH1107
R1, R2: 100k; R_Axial_DIN0207_L6.3mm_D2.5mm_P7.62mm_Horizontal
R3: 1k; R_Axial_DIN0207_L6.3mm_D2.5mm_P7.62mm_Horizontal
SW1: SW_SPDT; SW_E-Switch_EG1224_SPDT_Angled
SW2, SW3, SW4, SW5: SW_Push; SW_PUSH-12mm

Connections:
+3V3: Adalogger1.27 (3v3), GME_128128.1 (VCC)
GND: Adalogger1.25 (GND/GND), BZ1.2 (-), D2.1 (K), GME_128128.2 (GND), R2.1, SW1.3 (C), SW2.2, SW3.2, SW4.2, SW5.2
unnamed: Adalogger1.24 (A0/GPIO26), R1.1, R2.2
unnamed: Adalogger1.23 (A1/GPIO27), SW3.1
unnamed: Adalogger1.22 (A2/GPIO28), SW2.1
unnamed: Adalogger1.21 (A3/GPIO29), SW5.1
unnamed: Adalogger1.4 (D6/GPIO6), R3.1
unnamed: Adalogger1.5 (D9/GPIO9), GME_128128.7 (RST)
unnamed: Adalogger1.6 (D10/GPIO10), GME_128128.6 (CS)
unnamed: Adalogger1.7 (D11/GPIO11), GME_128128.5 (DC)
unnamed: Adalogger1.8 (D12/GPIO12), GME_128128.4 (SDA)
unnamed: Adalogger1.9 (D13/GPIO13), GME_128128.3 (SCL)
unnamed: Adalogger1.20 (D24/GPIO24), SW4.1
unnamed: Adalogger1.19 (D25/GPIO25), BZ1.1 (+)
unnamed: Adalogger1.11 (EN), SW1.2 (B)
unnamed: Adalogger1.12 (VBAT), R1.2
unnamed: D2.2 (A), R3.2

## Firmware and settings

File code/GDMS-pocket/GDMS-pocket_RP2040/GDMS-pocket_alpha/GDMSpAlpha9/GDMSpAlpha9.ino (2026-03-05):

/*
  GDMS-p_Alpha.ino

  
  - Feather RP2040 Adalogger
  - 1.5" SH1107 128x128 OLED (SPI) via U8g2
  - SD card via SdFat on SPI1 (OLED uses SW SPI to avoid conflicts)

  Based on:
  - POC_V04 structure/state machine/UI logic  :contentReference[oaicite:3]{index=3}
  - Log8 pin map + SH1107 offset note        :contentReference[oaicite:4]{index=4}

Alpha   -  Core functionality fully implemented
Alpha 2 - Word-aware wrapping 260228
Alpha 3 - Hold  to scroll 250228
Alpha 4 - List wrapping 
Alpha 5 - LED breathe and pop. 
Alpha 6 - Options A+B options menu
Alpha 7 - Sleep and wake, scroll bar + about in options menu
Alpha 8 - more LED options, scroll bar on CATS menu. 
Alpha 9 - Battery Indicator implementation

*/

#include <Arduino.h>
#include <ArduinoJson.h>
#include <U8g2lib.h>
#include <SPI.h>
#include <SdFat.h>


// =================== PINS (from Log8 known-good) ===================
// Buttons (active-low, INPUT_PULLUP). Wired pin -> GND
// Up=A1, Down=A2, A=A3, B=24
enum BtnId : uint8_t { BTN_A = 0, BTN_B = 1, BTN_UP = 2, BTN_DOWN = 3 };
const uint8_t BTN_PINS[4]  = { A3, 24, A1, A2 };
const char*   BTN_NAMES[4] = { "A(A3)", "B(24)", "UP(A1)", "DN(A2)" };

// Buzzer signal on D5 (passive buzzer module)
const uint8_t BUZZER_PIN = 6;

// External LED on D24 (anode via resistor -> D24, cathode -> GND)
const uint8_t LED_PIN = 25;

// OLED (software SPI) pin mapping per Log8:
// SCL/CLK=D13, SDA/DATA=D12, DC=D11, CS=D10, RST=D9
const uint8_t OLED_CLK = 13;
const uint8_t OLED_DAT = 12;
const uint8_t OLED_DC  = 11;
const uint8_t OLED_CS  = 10;
const uint8_t OLED_RST = 9;

// Battery monitor — external voltage divider: BAT → 100kΩ → A0 → 100kΩ → GND
// Center tap (A0) reads half the battery voltage; we double it in software.
const uint8_t BATTERY_PIN = A0;

// =================== BATTERY STATE ===================
float    battVoltage      = 4.2f;   // last measured battery voltage (V); starts optimistic
uint32_t lastBattSampleMs = 0;
const uint32_t BATT_SAMPLE_INTERVAL_MS = 5000; // sample every 5 s

// Voltage thresholds (LiPo 4.2V full -> ~3.2V cutoff)
// 3 fill levels: FULL=3 bars >=4.0V, OK=2 bars >=3.7V, LOW=1 bar >=3.5V, CRIT=0 bars <3.5V
enum BattLevel : uint8_t { BATT_CRIT = 0, BATT_LOW = 1, BATT_OK = 2, BATT_FULL = 3 };

BattLevel battLevelFromVoltage(float v) {
  if (v >= 4.0f) return BATT_FULL;
  if (v >= 3.7f) return BATT_OK;
  if (v >= 3.5f) return BATT_LOW;
  return BATT_CRIT;
}

// Take 8 ADC samples and average them; update battVoltage.
void sampleBattery() {
  analogReadResolution(12); // ensure 12-bit (0-4095)
  uint32_t sum = 0;
  for (int i = 0; i < 8; i++) {
    sum += analogRead(BATTERY_PIN);
    delay(1);
  }
  float raw = sum / 8.0f;
  float vA0 = (raw / 4095.0f) * 3.3f;
  battVoltage = vA0 * 2.0f; // undo the divider
}

// =================== OLED (U8g2) ===================
// Page-buffer constructor (lighter RAM). You can switch to _F_ later if desired.
// NOTE: If you see a 32px wrap/shift, apply the U8g2 SH1107 x_offset patch described in Log8.
U8G2_SH1107_128X128_1_4W_SW_SPI u8g2(
  U8G2_R0,
  /* clock=*/ OLED_CLK,
  /* data=*/  OLED_DAT,
  /* cs=*/    OLED_CS,
  /* dc=*/    OLED_DC,
  /* reset=*/ OLED_RST
);

// =================== SLEEP / WAKE ===================
bool     deviceSleeping = false;  // true while OLED is blanked
uint32_t lastActivityMs = 0;      // updated on every button press

// =================== USER SETTINGS (runtime, not persisted) ===================
// These are controlled via the Options menu and may change at runtime.

// --- Buzzer ---
// buzzerEnabled already declared below with buzzer state vars

// Buzzer volume: two levels via a series-resistor workaround in software
// (we vary tone duration; hardware resistor remains the real fix,
//  but shorter bursts feel meaningfully quieter)
enum BuzVol  : uint8_t { BUZ_VOL_SOFT = 0, BUZ_VOL_LOUD = 1 };
BuzVol buzVolume = BUZ_VOL_LOUD; // default: loud

// --- LED master on/off and pop on/off ---
bool ledEnabled    = true;  // master LED switch (breathing + pop)
bool ledPopEnabled = true;  // pop flash on button press (requires ledEnabled)

// --- LED brightness (affects BREATH_MAX and POP_BRIGHTNESS) ---
enum LedBright : uint8_t { LED_BRIGHT_LOW = 0, LED_BRIGHT_MED = 1, LED_BRIGHT_HIGH = 2 };
LedBright ledBrightness = LED_BRIGHT_MED; // default: medium

// Lookup tables indexed by LedBright
const uint8_t  LED_BREATH_MAX_TBL[3] = { 20,  80, 180 };
const uint8_t  LED_POP_TBL[3]        = { 25, 128, 255 };

// --- Breath speed ---
enum BreathSpd : uint8_t { BREATH_FAST = 0, BREATH_MED = 1, BREATH_SLOW = 2 };
BreathSpd breathSpeed = BREATH_MED; // default: medium

// Lookup table indexed by BreathSpd (ms per full cycle)
const uint32_t BREATH_PERIOD_TBL[3] = { 500, 3000, 10000 };

// --- Sleep timeout ---
enum SleepTimeout : uint8_t { SLEEP_5MIN = 0, SLEEP_10MIN = 1, SLEEP_30MIN = 2, SLEEP_NEVER = 3 };
SleepTimeout sleepTimeout = SLEEP_5MIN; // default: 5 minutes

// Lookup table: timeout in milliseconds (0 = never)
const uint32_t SLEEP_TIMEOUT_TBL[4] = {
  5UL  * 60UL * 1000UL,  // 5 min
  10UL * 60UL * 1000UL,  // 10 min
  30UL * 60UL * 1000UL,  // 30 min
  0UL                    // never
};

// =================== LED BREATHING ===================
// Sine-wave breathing: LED fades in and out continuously.
// On button press a full-brightness "pop" interrupts, then breathing resumes.
// (BREATH_MIN is always 0; other params are read from tables above at runtime.)
const uint32_t POP_DURATION_MS  = 100;  // how long the pop lasts

bool     ledPopActive = false;   // true while the pop flash is showing
uint32_t ledPopEndMs  = 0;       // when the pop should end
uint32_t ledBreathOffset = 0;    // phase offset so breath resumes smoothly after pop

// =================== BUTTONS (debounce + edge detect + hold-repeat) ===================
bool wasPressed[4] = {false, false, false, false};
uint32_t lastPressMs[4] = {0, 0, 0, 0};
const uint16_t DEBOUNCE_MS = 40;

// Hold-to-repeat: only BTN_UP and BTN_DOWN auto-repeat; A and B are edge-only.
const uint32_t HOLD_DELAY_MS  = 500;  // pause before repeat starts
const uint32_t HOLD_REPEAT_MS = 100;  // interval between repeated fires
uint32_t holdStartMs[4]  = {0, 0, 0, 0}; // when the button was first confirmed pressed
uint32_t lastRepeatMs[4] = {0, 0, 0, 0}; // last time a repeat event fired
bool     holdActive[4]   = {false, false, false, false}; // button is currently held

// =================== NON-BLOCKING BUZZER ===================

bool buzzerEnabled = false; //master switch (to be made otggleable in options menu sousa260228)
bool buzOn = false;
uint32_t buzOffMs = 0;

void buzzerStart(uint16_t freq, uint16_t durMs) {
  if (!buzzerEnabled) return;
  // Soft volume: halve the duration so the burst feels shorter/quieter
  if (buzVolume == BUZ_VOL_SOFT) durMs = max((uint16_t)1, (uint16_t)(durMs / 2));
  tone(BUZZER_PIN, freq);
  buzOn = true;
  buzOffMs = millis() + durMs;
}

void buzzerUpdate(uint32_t now) {
  if (buzOn && (int32_t)(now - buzOffMs) >= 0) {
    noTone(BUZZER_PIN);
    buzOn = false;
  }
}

void ledPop() {
  if (!ledEnabled || !ledPopEnabled) return;
  uint32_t now = millis();
  uint32_t period = BREATH_PERIOD_TBL[breathSpeed];
  ledBreathOffset = now % period;
  ledPopActive = true;
  ledPopEndMs  = now + POP_DURATION_MS;
  analogWrite(LED_PIN, LED_POP_TBL[ledBrightness]);
}

void ledUpdate(uint32_t now) {
  if (!ledEnabled) {
    analogWrite(LED_PIN, 0);
    ledPopActive = false;
    return;
  }
  if (ledPopActive) {
    if ((int32_t)(now - ledPopEndMs) >= 0) {
      ledPopActive = false;
      // Fall through immediately to resume breath on this same tick
    } else {
      return; // still popping — don't touch the LED
    }
  }

  // Triangle-wave breath using runtime period and brightness settings.
  uint32_t period   = BREATH_PERIOD_TBL[breathSpeed];
  uint8_t  breathMax = LED_BREATH_MAX_TBL[ledBrightness];
  uint32_t t = (now + ledBreathOffset) % period;
  uint8_t  val;
  if (t < period / 2) {
    val = (uint8_t)((uint32_t)breathMax * 2 * t / period);
  } else {
    val = (uint8_t)((uint32_t)breathMax * 2 * (period - t) / period);
  }
  analogWrite(LED_PIN, val);
}

// =================== SD (Adafruit Feather RP2040 Adalogger) ===================
#define SD_CS_PIN 23
SdFat SD;
SdSpiConfig sdConfig(SD_CS_PIN, DEDICATED_SPI, SD_SCK_MHZ(16), &SPI1);

// =================== APP STATE ===================
static const uint8_t MAX_CATS = 40;
String categories[MAX_CATS];
uint8_t catCount = 0;

int16_t cursor = 0;     // which category is selected
int16_t scrollTop = 0;  // first visible row

static const uint8_t MAX_FILES = 60;
String files[MAX_FILES];
uint8_t fileCount = 0;

int16_t fileCursor = 0;
int16_t fileScrollTop = 0;

enum UiMode : uint8_t { MODE_CATS = 0, MODE_FILES = 1, MODE_TABLE = 2, MODE_OPTIONS = 3, MODE_ABOUT = 4 };
UiMode mode     = MODE_CATS;
UiMode prevMode = MODE_CATS; // mode to return to when exiting options

// Options menu
const uint8_t OPT_COUNT = 8;   // Buzzer,BuzVol,LEDon,LEDpop,LEDBrt,Breathe,Sleep,About
int8_t optCursor = 0;          // which row is selected (0–OPT_COUNT-1)

// A+B combo detection
bool     abComboFired  = false;   // prevent repeated firing while both held
uint32_t abComboArmMs  = 0;       // when the second button of the pair came down
const uint16_t AB_COMBO_MS = 80;  // both must be held within this window

String selectedCat;
String selectedFile;

String currentEntry;     // the chosen CSV row (raw line)
uint16_t rollCount = 0;  // how many rerolls in this table view
int16_t tableScrollLine = 0; // which wrapped line to start drawing from

// =================== OLED THROTTLE POLICY ===================
uint32_t lastInputMs = 0;
uint32_t lastOledMs = 0;
const uint16_t OLED_PERIOD_MS = 90;
const uint16_t OLED_IDLE_AFTER_MS = 0;

// ---------- helpers ----------
// static inline String stripCsvExt(const String& s) {
//   if (s.length() >= 4) {
//     String tail = s.substring(s.length() - 4);
//     tail.toLowerCase();
//     if (tail == ".csv") return s.substring(0, s.length() - 4);
//   }
//   return s;
// }

void showSplashScreen(uint16_t ms = 2000) {
  const uint32_t t0 = millis();

  while ((uint32_t)(millis() - t0) < ms) {
    u8g2.firstPage();
    do {
      // Big title block
      u8g2.setFont(u8g2_font_8x13_tf);

      u8g2.drawStr(0, 18,  "GOBLINOID");
      u8g2.drawStr(0, 36,  "DUNGEON");
      u8g2.drawStr(0, 54,  "MASTERING");
      u8g2.drawStr(0, 72,  "SYSTEM");

      // Footer
      u8g2.setFont(u8g2_font_6x12_tf);
      u8g2.drawStr(0, 102, "-Alexander Sousa");
      u8g2.drawStr(0, 118, "2026");
    } while (u8g2.nextPage());

    delay(10); // small yield
  }
}


static inline bool endsWithCsv(const String& s) {
  if (s.length() < 4) return false;
  String tail = s.substring(s.length() - 4);
  tail.toLowerCase();
  return tail == ".csv";
}

static inline bool endsWithJson(const String& s) {
  if (s.length() < 5) return false;
  String tail = s.substring(s.length() - 5);
  tail.toLowerCase();
  return tail == ".json";
}


static inline String stripCsvOrJsonExt(const String& s) {
  String lower = s;
  lower.toLowerCase();
  if (lower.endsWith(".csv"))  return s.substring(0, s.length() - 4);
  if (lower.endsWith(".json")) return s.substring(0, s.length() - 5);
  return s;
}

// Conservative ellipsize by character count (works fine for your mostly-ASCII UI labels)
static inline String ellipsize(const String& s, uint8_t maxChars) {
  if (s.length() <= maxChars) return s;
  if (maxChars <= 3) return s.substring(0, maxChars);
  return s.substring(0, maxChars - 3) + "...";
}

// ---------------------------------------------------------------------------
// Word-aware line wrapper — Arduino-compatible (no templates, no lambdas)
// ---------------------------------------------------------------------------
// Each wrapped line is described by a WrapLine: either a slice of the source
// string (via start+len) or a pre-built buffer (isOwned=true) for hyphenated
// hard-cuts.  MAX_WRAP_LINES caps memory; entries beyond it are silently lost
// (a safety net — typical entries are well under this limit).
// ---------------------------------------------------------------------------

const uint8_t  WRAP_CHARS  = 20;   // characters per display line (21st column reserved for scrollbar)
const uint16_t MAX_WRAP_LINES = 64; // max lines we'll ever store

struct WrapLine {
  char     buf[WRAP_CHARS + 1]; // null-terminated text for this line
};

// Shared buffer reused each time buildWrappedLines() is called.
// Declared at file scope so it lives in static RAM, not the call stack.
static WrapLine  wrapLines[MAX_WRAP_LINES];
static uint16_t  wrapLineCount = 0;

// Helper: copy ptr[0..pLen-1] into wrapLines[], appending '-' if hyphenSuffix.
static void wrapEmitLine(const char* ptr, uint8_t pLen, bool hyphenSuffix) {
  if (wrapLineCount >= MAX_WRAP_LINES) return;
  WrapLine& wl = wrapLines[wrapLineCount++];
  uint8_t copyN = (pLen <= WRAP_CHARS) ? pLen : WRAP_CHARS;
  if (hyphenSuffix && copyN == WRAP_CHARS) copyN = WRAP_CHARS - 1;
  memcpy(wl.buf, ptr, copyN);
  if (hyphenSuffix) { wl.buf[copyN] = '-'; copyN++; }
  wl.buf[copyN] = '\0';
}

// Populate wrapLines[] for string s at WRAP_CHARS columns.
// Returns number of lines produced (also stored in wrapLineCount).
static uint16_t buildWrappedLines(const String& s) {
  wrapLineCount = 0;
  const uint8_t  CPL = WRAP_CHARS;
  const uint16_t len = s.length();
  const char*    src = s.c_str();

  uint16_t i        = 0;  // read cursor in s
  uint8_t  lineLen  = 0;  // chars accumulated on the current line
  uint16_t lineStart = 0; // index in s where current line's content begins

  while (i < len) {
    char c = src[i];

    // ── Explicit newline ────────────────────────────────────────────────────
    if (c == '\n') {
      wrapEmitLine(src + lineStart, lineLen, false);
      i++;
      lineStart = i;
      lineLen   = 0;
      continue;
    }

    // ── Find end of next word ───────────────────────────────────────────────
    uint16_t wordEnd = i;
    while (wordEnd < len && src[wordEnd] != ' ' && src[wordEnd] != '\n') {
      wordEnd++;
    }
    uint16_t wordLen16 = wordEnd - i;
    uint8_t  wordLen   = (wordLen16 > 255) ? 255 : (uint8_t)wordLen16;

    // Eat leading space at the start of a line (prevents accidental indent)
    if (wordLen == 0 && c == ' ' && lineLen == 0) {
      lineStart++;
      i++;
      continue;
    }

    uint8_t spaceNeeded = (lineLen > 0) ? 1 : 0;

    // ── Word fits on current line ───────────────────────────────────────────
    if (lineLen + spaceNeeded + wordLen <= CPL) {
      if (lineLen > 0 && c == ' ') {
        lineLen++; // include the separating space in this line's slice
        i++;
      }
      lineLen += wordLen;
      i       += wordLen;

    // ── Word is too long to ever fit — hyphenated hard-cut ─────────────────
    } else if (wordLen >= CPL) {
      if (lineLen > 0) {
        wrapEmitLine(src + lineStart, lineLen, false);
        lineStart += lineLen;
        lineLen    = 0;
      }
      // Eat inter-word space
      if (i < len && src[i] == ' ') { lineStart++; i++; }

      uint16_t remaining = wordEnd - i;
      while (remaining > 0) {
        if (remaining <= (uint16_t)CPL) {
          // Last chunk — no hyphen, leave open for possible continuation
          lineLen    = (uint8_t)remaining;
          i         += remaining;
          remaining  = 0;
        } else {
          // Intermediate chunk — emit with hyphen
          uint8_t chunkChars = CPL - 1;
          wrapEmitLine(src + lineStart, chunkChars, true);
          i         += chunkChars;
          lineStart  = i;
          lineLen    = 0;
          remaining -= chunkChars;
        }
      }

    // ── Word doesn't fit — wrap to next line ───────────────────────────────
    } else {
      wrapEmitLine(src + lineStart, lineLen, false);
      lineStart += lineLen;
      lineLen    = 0;
      // Eat inter-word space that triggered the wrap
      if (i < len && src[i] == ' ') { lineStart++; i++; }
      // Re-evaluate the same word on the fresh line
    }
  }

  // Flush any remaining content (or emit at least one line for empty input)
  if (lineLen > 0 || wrapLineCount == 0) {
    wrapEmitLine(src + lineStart, lineLen, false);
  }

  return wrapLineCount;
}

// Convenience: just return the line count (same as buildWrappedLines but
// named clearly for the scroll-math call site).
static uint16_t countWrappedLines(const String& s, uint8_t /*charsPerLine*/) {
  return buildWrappedLines(s);
}
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
void loop() {
  uint32_t now = millis();
  buzzerUpdate(now);

  // LED breathing + pop
  ledUpdate(now);

  // ── Battery sampling (every 5 s, non-blocking) ──────────────────────────
  if (now - lastBattSampleMs >= BATT_SAMPLE_INTERVAL_MS) {
    lastBattSampleMs = now;
    sampleBattery();
  }

  // ── Sleep timeout check ─────────────────────────────────────────────────
  {
    uint32_t tmo = SLEEP_TIMEOUT_TBL[sleepTimeout];
    if (!deviceSleeping && tmo > 0 && (now - lastActivityMs >= tmo)) {
      deviceSleeping = true;
      u8g2.firstPage();
      do { /* blank frame */ } while (u8g2.nextPage());
    }
  }

  // ── A+B combo → open options from any mode ──────────────────────────────
  {
    bool aHeld = (digitalRead(BTN_PINS[BTN_A]) == LOW);
    bool bHeld = (digitalRead(BTN_PINS[BTN_B]) == LOW);

    if (aHeld && bHeld) {
      if (!abComboFired) {
        // Require both to have been held for at least AB_COMBO_MS together
        if (abComboArmMs == 0) abComboArmMs = now;
        if (now - abComboArmMs >= AB_COMBO_MS && mode != MODE_OPTIONS) {
          abComboFired = true;
          prevMode = mode;
          mode = MODE_OPTIONS;
          ledPop();
          uiRedraw();
        }
      }
    } else {
      // One or both released — reset combo state
      abComboArmMs = 0;
      abComboFired = false;
    }
  }

  // read buttons — edge detect + hold-to-repeat for UP/DOWN
  for (int i = 0; i < 4; i++) {
    bool curPressed = (digitalRead(BTN_PINS[i]) == LOW);
    bool isRepeatBtn = (i == BTN_UP || i == BTN_DOWN);

    // ── Falling edge (new press) ──────────────────────────────────────────
    if (!wasPressed[i] && curPressed) {
      if (now - lastPressMs[i] >= DEBOUNCE_MS) {
        lastPressMs[i]  = now;
        wasPressed[i]   = true;
        holdActive[i]   = true;
        holdStartMs[i]  = now;
        lastRepeatMs[i] = now;
        onButtonPressed((BtnId)i);
        Serial.print(BTN_NAMES[i]);
        Serial.println(" PRESSED");
      }
    }

    // ── Hold-to-repeat (UP and DOWN only) ────────────────────────────────
    if (wasPressed[i] && curPressed && isRepeatBtn && holdActive[i]) {
      if (now - holdStartMs[i] >= HOLD_DELAY_MS) {
        if (now - lastRepeatMs[i] >= HOLD_REPEAT_MS) {
          lastRepeatMs[i] = now;
          onButtonPressed((BtnId)i);
        }
      }
    }

    // ── Rising edge (release) ─────────────────────────────────────────────
    if (wasPressed[i] && !curPressed) {
      wasPressed[i] = false;
      holdActive[i] = false;
    }
  }

  // Optional periodic refresh hook (generally unnecessary with page-buffer redraw-on-input)
  if ((now - lastOledMs >= OLED_PERIOD_MS) && (now - lastInputMs >= OLED_IDLE_AFTER_MS)) {
    lastOledMs = now;
    // uiRedraw();
  }

  delay(1);
}

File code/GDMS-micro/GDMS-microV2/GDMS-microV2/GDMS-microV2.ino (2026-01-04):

#include <Wire.h>
#include <U8g2lib.h>

// ===================== OLED (U8x8 text mode) =====================
U8X8_SSD1306_128X64_NONAME_HW_I2C u8x8(U8X8_PIN_NONE);

// ===================== PINS =====================
const uint8_t PIN_BTN_LEFT   = 2;  // back (active LOW)
const uint8_t PIN_BTN_CENTER = 3;  // forward (active LOW)
const uint8_t PIN_BTN_X      = 4;  // select / action (active LOW)

const uint8_t PIN_BUZZER     = 5;  // passive buzzer signal
const uint8_t PIN_LED        = 6;  // PWM LED

// ===================== LED BREATH + POP =====================
const uint8_t LED_MIN = 5;
const uint8_t LED_MAX = 20;
const uint8_t LED_POP = 30;

const uint16_t BREATH_STEP_MS = 50;
const uint16_t POP_MS         = 60;

uint8_t ledLevel = LED_MIN;
int8_t  ledDir   = +1;
unsigned long lastBreathMs = 0;

bool popActive = false;
unsigned long popUntilMs = 0;

void ledInit() {
  pinMode(PIN_LED, OUTPUT);
  analogWrite(PIN_LED, LED_MIN);
}

void ledPop() {
  popActive = true;
  popUntilMs = millis() + POP_MS;
  analogWrite(PIN_LED, LED_POP);
}

void ledUpdate() {
  unsigned long now = millis();

  if (popActive) {
    if ((long)(now - popUntilMs) >= 0) {
      popActive = false;
      analogWrite(PIN_LED, ledLevel);
    }
    return;
  }

  if (now - lastBreathMs >= BREATH_STEP_MS) {
    lastBreathMs = now;

    int16_t next = (int16_t)ledLevel + ledDir;
    if (next >= LED_MAX) { next = LED_MAX; ledDir = -1; }
    else if (next <= LED_MIN) { next = LED_MIN; ledDir = +1; }

    ledLevel = (uint8_t)next;
    analogWrite(PIN_LED, ledLevel);
  }
}

// ===================== BUZZER =====================
bool buzOn = false;
unsigned long buzUntilMs = 0;

void buzzerInit() {
  pinMode(PIN_BUZZER, OUTPUT);
  noTone(PIN_BUZZER);
}

void buzzerBeepHz(uint16_t hz, uint16_t ms) {
  tone(PIN_BUZZER, hz);
  buzOn = true;
  buzUntilMs = millis() + ms;
}

void buzzerUpdate() {
  if (!buzOn) return;
  if ((long)(millis() - buzUntilMs) >= 0) {
    buzOn = false;
    noTone(PIN_BUZZER);
  }
}

// ===================== BUTTONS (DEBOUNCE, NO STRUCTS) =====================
const unsigned long DEBOUNCE_MS = 30;

bool left_lastReading=false,   left_stablePressed=false,   left_latched=false;
bool ctr_lastReading=false,    ctr_stablePressed=false,    ctr_latched=false;
bool x_lastReading=false,      x_stablePressed=false,      x_latched=false;

unsigned long left_lastFlipMs=0, ctr_lastFlipMs=0, x_lastFlipMs=0;

void buttonsInit() {
  pinMode(PIN_BTN_LEFT,   INPUT_PULLUP);
  pinMode(PIN_BTN_CENTER, INPUT_PULLUP);
  pinMode(PIN_BTN_X,      INPUT_PULLUP);
}

bool justPressed(uint8_t pin,
                 bool &lastReading,
                 bool &stablePressed,
                 bool &latched,
                 unsigned long &lastFlipMs)
{
  bool readingPressed = (digitalRead(pin) == LOW);

  if (readingPressed != lastReading) {
    lastReading = readingPressed;
    lastFlipMs = millis();
  }

  if ((millis() - lastFlipMs) > DEBOUNCE_MS) {
    stablePressed = lastReading;
  }

  if (stablePressed && !latched) {
    latched = true;
    return true;
  }

  if (!stablePressed) latched = false;
  return false;
}

// helper: stable pressed state (for combos like LEFT+CENTER)
bool isHeldLeft()   { return left_stablePressed; }
bool isHeldCenter() { return ctr_stablePressed;  }
bool isHeldX()      { return x_stablePressed;    }

// ===================== SYSTEM: MODES + APPLETS =====================
enum UiMode : uint8_t { MODE_HOME = 0, MODE_APPLET = 1 };
UiMode mode = MODE_HOME;

enum Applet : uint8_t { APP_DICE = 0, APP_NAMES = 1, APP_ROOM = 2, APPLET_COUNT = 3 };
uint8_t applet = APP_DICE;

// ===================== DICE APPLET =====================
enum DicePage : uint8_t {
  P_D4 = 0,
  P_D6,
  P_D8,
  P_D10,
  P_D12,
  P_D20,
  P_D100,
  P_DICE_COUNT
};

uint8_t dicePage = P_D20;
uint16_t lastRoll = 0;
bool hasRoll = false;

uint16_t rollDie(uint16_t sides) {
  return (uint16_t)random(sides) + 1;
}

uint16_t sidesForDicePage(uint8_t p) {
  switch (p) {
    case P_D4:   return 4;
    case P_D6:   return 6;
    case P_D8:   return 8;
    case P_D10:  return 10;
    case P_D12:  return 12;
    case P_D20:  return 20;
    case P_D100: return 100;
    default:     return 20;
  }
}

uint16_t freqForDicePage(uint8_t p) {
  switch (p) {
    case P_D4: return 988;
    case P_D6: return 880;
    case P_D8: return 784;
    case P_D10:return 698;
    case P_D12:return 659;
    case P_D20:return 587;
    case P_D100:return 523;
    default: return 660;
  }
}

const char label_d4[]   PROGMEM = "D4";
const char label_d6[]   PROGMEM = "D6";
const char label_d8[]   PROGMEM = "D8";
const char label_d10[]  PROGMEM = "D10";
const char label_d12[]  PROGMEM = "D12";
const char label_d20[]  PROGMEM = "D20";
const char label_d100[] PROGMEM = "D100";

const char* const DICE_LABELS[] PROGMEM = {
  label_d4, label_d6, label_d8, label_d10, label_d12, label_d20, label_d100
};

void getDiceLabel(char* out, uint8_t outSize) {
  const char* p = (const char*)pgm_read_ptr(&DICE_LABELS[dicePage]);
  strncpy_P(out, p, outSize - 1);
  out[outSize - 1] = '\0';
}

// ===================== NAMES APPLET (simple list for now) =====================
const char n0[] PROGMEM = "Hera";
const char n1[] PROGMEM = "Torin";
const char n2[] PROGMEM = "Ginny";
const char n3[] PROGMEM = "Gant";
const char n4[] PROGMEM = "Olga";
const char n5[] PROGMEM = "Dendor";
const char n6[] PROGMEM = "Ygrid";
const char n7[] PROGMEM = "Pike";
const char n8[] PROGMEM = "Sarda";
const char n9[] PROGMEM = "Brigg";
const char n10[] PROGMEM = "Zorli";
const char n11[] PROGMEM = "Yorin";
const char n12[] PROGMEM = "Jorgena";
const char n13[] PROGMEM = "Trogin";
const char n14[] PROGMEM = "Riga";
const char n15[] PROGMEM = "Barton";
const char n16[] PROGMEM = "Katrina";
const char n17[] PROGMEM = "Egrim";
const char n18[] PROGMEM = "Elsa";
const char n19[] PROGMEM = "Skylark";
const char n20[] PROGMEM = "Orgo";
const char n21[] PROGMEM = "Fargrim";
const char n22[] PROGMEM = "Gruner";
const char n23[] PROGMEM = "Torbin";
const char n24[] PROGMEM = "Malik";
const char n25[] PROGMEM = "Flea";
const char n26[] PROGMEM = "Crow";
const char n27[] PROGMEM = "Rusty";
const char n28[] PROGMEM = "Spike";
const char n29[] PROGMEM = "Frond";
const char n30[] PROGMEM = "Yuorg";
const char n31[] PROGMEM = "Willow";
const char n32[] PROGMEM = "Blinky";
const char n33[] PROGMEM = "Red";
const char n34[] PROGMEM = "Papa";
const char n35[] PROGMEM = "Slim";
const char n36[] PROGMEM = "Shorty";
const char n37[] PROGMEM = "Oak";
const char n38[] PROGMEM = "Shadow";
const char n39[] PROGMEM = "Sunny";
const char n40[] PROGMEM = "Morg";

const char* const NAME_LIST[] PROGMEM = {
  n0,n1,n2,n3,n4,n5,n6,n7,n8,n9,n10,n11,n12,n13,n14,n15,n16,n17,n18,n19, n20, n21, n22, n23, n24, n25, n26, n27, n28, n29, n30, n31, n32, n33, n34, n35, n36, n37, n38, n39, n40
};

const uint8_t NAME_COUNT = sizeof(NAME_LIST) / sizeof(NAME_LIST[0]);
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

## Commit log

2025-12-25 adding data files
    [npc_traits.csv]
2025-12-25 upload more data and resructure
    [npc_traits.csv]
2025-12-25 new files and rearranged structure
    [encounter.csv, equipment_aspects.csv, grafitti.csv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]
2025-12-27 fixed inaccurate V02 code
    [GDMS-pocket-V02.ino]
2025-12-27 new LED features
    breathing and pop on press
2025-12-28 mini-dice roller for arduino nano
    Sketch design for the nano paying heed to limitted storage and RAM
2025-12-29 writing for arduino nano
    Much code writen for the arduino nano such that an external SD module is not needed. Spartan UI redesign, and other flash memeory and RAM saving measures taken. No SD card means all lists for random rolls are hard coded into the flash memory of the nano.
    Log updated to reflect changes.
    [GDMS-microV2.ino, GDMS-pocket-V02.ino, GDMS-pocket-V03.ino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]
2026-01-02 beginning CircuitPython
2026-01-04 MCU boards comparisons
2026-01-04 editting readme to reflect wiring changes
2026-01-06 A and B button flip
    [POC_V04.ino]
2026-01-07 Implemented JSON recipe v1
    JSON Recipe System – V1 Summary
    What V1 Accomplishes
    V1 introduces JSON-based generators (“recipes”) that behave exactly like CSV tables from the user’s point of view, while allowing internally chained rolls.
    Key capabilities:
    JSON recipes appear in the UI alongside CSV tables
    .json files are listed and selectable just like .csv
    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
2026-01-07 Updated to remove deprecated functions
    deprecated arduino Json functions (dynamic vs static) eliminate din favor of newer functions.
2026-01-08 monster table uploads
    [monster_generator.csv, monster_mutations.csv]
2026-01-10 Revise README for clarity and additional details
    Updated README to enhance clarity and structure, including hardware pin plan, library table, and functional specifications.
2026-01-11 better test which includes all components - and renamed
    sketch tests 1.5" 128 x 128 OLED, 4 buttons, passive buzzer, and LED.
    [testSketch.ino]
2026-01-11 editting data files.
    [About.csv, Effect.csv, Trigger.csv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]
2026-01-11 added class.csv for PC generation
    [class.csv]
2026-01-11 adding weights to CSV files. correcting to eliminate "," or blank gnerations. Created feature summary / changelog
    [monsters.csv]
2026-01-11 -added code to sort category entries by extension (JSON firtst).
    -Added a JSON recipe for monster generation
    -split multi-column csv's into seperate files
    [About.csv, level.csv, monster_generator.csv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]
2026-01-14 Dice and potion csvs added
    [D10.csv, D12.csv, D20.csv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]
2026-01-14 rearranged rows for test
    [About.csv]
2026-01-14 added JSON functionality to repeatedly sample csv files and concatenate generated data. Concatenation can be via commas or newlines.
    [startingGear.csv]
2026-01-14 changed file extensions and eliminated duplicate files.
    [all.csv, encounters.csv]
2026-01-14 eddited recipes and CSVs
    [3d6.csv, names.csv]
2026-01-14 editted JSON
    [_potionsMagnitude.csv, _potionsType.csv]
2026-01-19 battery meter test sketch and file renaming
2026-01-25 creating some KiCAD files for PCB design
    [GDMS-pocket.kicad_pcb, GDMS-pocket.kicad_sch]
2026-01-26 uploading schematic data in KiCAD and manufacturer data on 1.5" OLED SPI display
2026-02-04 Uploading KiCad Files
    [GDMS-pocket.kicad_pcb]
2026-02-05 removing KiCad files
    [GDMS-pocket.kicad_pcb, GDMS-pocket.kicad_sch]
2026-02-17 arduino shenanegins
2026-02-28 fixed data files, added new files and json recipes,
    [3d6.csv, About.csv, Effect.csv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]
2026-02-28 new battery indicator sketch
2026-02-28 altered log. and GDMSpAlpha code to incorporate beginning of Settings menu for buzzer and other downstream options.
    [GDMSAlpha1.ino]
2026-02-28 roll back changes manually via ctrl+z and updated code to match real button pins.
2026-08-26 Document GDMS-pocket Companion App plans in README
    Added a planned section for the GDMS-pocket Companion App, detailing its concept, aesthetic, device interaction, and open questions.
2026-08-28 tested an dimplemented SD card reader mode
    allows users to edit SD card contents by simply plugging in the device.
2026-10-10 Add v2 tag filter design notes
    Captures the planned tag-based Setting/filter feature for GDMS-pocket 2:
    weight-first quoted CSV with tag columns, AND filtering, pre-screen scan,
    tag index, and JSON recipe handling. Open questions left open.
    Claude-Session: https://claude.ai/code/session_019EqQ7Y7tYah7nw7wjDGfBM
